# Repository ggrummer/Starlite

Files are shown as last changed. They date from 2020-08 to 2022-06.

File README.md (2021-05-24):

# Starlite
6 and 8-point stars using an FPGA to produce numerous patterns via a simple instruction set.
One doesn't need to know anything about FPGAs to create your own custom displays.
Refer to the "Documents" directory for project documents.
The Eagle directory has the schematic and the board design files.
The Mechanical directory has the 2D CAD files for laser cutting acrylic into star shapes, the 3D CAD files for the optional back covers and 3D CAD files for optional side covers.
The SolUP12 directory has all the FPGA files for the no longer recommended Lattice iCEcube2 build enviorment.
The SolRadi directory has all the FPGA files for the recommended Lattice Radiant build enviorment.

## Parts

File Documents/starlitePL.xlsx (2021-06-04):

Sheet: Assy Parts List
Starlite Assembly Parts List
Description | Qty | Manufacture | Part Number | Distributer | Cost | Comment
Outer Acrylic | 1 | Pololu | 7328, 1/8" | Pololu | $22.55
Inner Acrylic | 1 | Pololu | 7328, 1/16" | Pololu | $22.55 | See Notes Below
Screw, Polycarb, 4-40, 3/8" | 8 | Essentra Comp | 010440W037PC | Digi-Key | $4.88
Standoff, Nylon, 4-40, 5/8" | 4 | Essentra Comp | 15TSP036 | Digi-Key | $3.40
NeoPixel RGB Strip 60 LEDs | 1 | Sparkfun | COM-14730 | Digi-Key | $14.95 | See Notes Below
PCB | 1 | OSH Park | STARLITEMAIN | OSH Park | $15.49 | 1/3 of order
PCB Parts |  |  |  |  | $34.14
Total |  |  |  |  | $117.96
USB Micro Wall Adapter | 1 | CUI | SWI10-5-N-MUB | Digi-Key | $8.50 | Optional
Notes: | Inner acrylic can be 1/8" thick, but it will be harder to solder the LED strips to the pin headers
 | Each point of a star uses a strip of 7 LEDs, so the 60 LED strip must be cut up
 | Sparkfun LED Strip is obsolete. Any 60 LED per meter strip, 4 or 5mm wide, and uses SK6812 or
 |  | WS2812B LEDs will work.
 |  | Alternates are:
 |  | Manufacture | Part Number | Distributer | Cost | Comment
 |  | SuperLightingLED | SK6812-3535-60W5 | Direct, China | $9.98 | White, 1 meter
 |  | Alitove | AL2812WH120NP2M5MM | Amazon | $16.99 | White, 2 meters
 |  | H/A | B093CWF55Y | Amazon | $17.69 | White, 2 meters

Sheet: PCB Parts List
Starlite PCB Parts Parts List |  |  |  |  |  | Rev 5
Description | Ref Des | Qty | Manufacture | Part Number | Distributer | Cost
iCE40UP FPGA Daughter Board | U1 | 1 | TinyVision | Upduino-V3.0 | Tindie | $24.00
8-bit Transceiver 20DIP | U2 | 1 | TI | SN74AHCT245N | Digi-Key | $0.53
USB Micro B Breakout Board | JP9 | 1 | Adafruit | 1833 | Digi-Key | $1.50
Diode, Schottky, Axial, 1A, 20V | D1 | 1 | MCC | 1N5817-TP | Digi-Key | $0.32
Cap 0.1uF, 50V X7R, Radial | C1, C2, C5 | 3 | Kemet | C326C104K5R5TA | Digi-Key | $0.66
Cap 100uF, 16V, Alum, Radial | C3, C4 | 2 | Rubycon | 16ML100MEFC6.3X7 | Digi-Key | $0.44
Switch, Tactile | S1, S3 | 2 | TI | 1-1825027-1 | Digi-Key | $0.52
Switch, Slide | S2 | 1 | C&K | L102021ML04Q | Digi-Key | $2.09
Pin Header, 3pin, 50 mil Pitch | JP1-8 or JP11-16 | 8 | Preci-Dip | 850-80-003-10-001101 | Digi-Key | $4.08
 |  |  |  |  |  | $0.00
Total |  |  |  |  |  | $34.14
Notes: | 8-point star uses JP1-8
 | 6-point star uses JP11-16

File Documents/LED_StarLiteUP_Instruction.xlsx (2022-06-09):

LED Lite Instruction Creator |  |  |  | Rev 1.8
By: Grant Grummer
Command | 4 | See below | One Byte
Address/Duration/Loops | 8 | See below | 6/8/8 Bits
Brightness/Qty/Control | 64 | See below | One Byte
Blue | 0 | 15 max | One Nibble
Green | 3 | 15 max | One Nibble
Red | 15 | 15 max | One Nibble
Instruction in Hex |  | 4084003F | 32 Bits
 | [31:28] | [27:20] | [19:12] | [11:0]
Instruction Description | Command Number | Address/Duration/ Loops/Hours On | Brightness/Qty/Hours Off/ Control | Color/Hours Delayed
Blackout display | 0
Delay 1 | 1 | Duration, 255 max, 0 is a random delay
Finish 3 | 2
Set one lite with random address and/or color | 3 | Address = 0 to 63, random = 64 | Brightness | 0 = current
 |  |  |  | 1 = new 4
 |  |  |  | 3 = new no rep 6
Set one lite | 4 | Address, 0 to 63 | Brightness | Color
Chase (lites rap around) | 5 | Offset size [25:20] 2 | 0 = decrement lite offset,
 |  |  | 1 = increment lite offset,
 |  |  | 2 = zero lite offset
Reserved | 6
Fade in & out | 7 | Incr lower limit [25:24] | 0 = disable fading,
 |  | Decr upper limit [23:22] | 1 = enable fading
 |  | Speed Up [21:20]
Loop the previous x number of instructions | 8 | Number of loops, 255 for infinite loop | Qty of instructions = loop instruction line number - start instruction number. 255 max instructions.
Set random color palette | 9 | Color number 0 to 15 |  | Color
Offset lite instruction by 1 to each star point, block points | 10 |  | 0 = disable point offset, | Block individual points from changing
 |  |  | 1 = enable point offset
Rainbow colors | 11 |  | 0 = disable,
 |  |  | 1 = enable
Reserved | 12
Auto Timeout 5 | 13 | Hours on: 31 max, 0 always on (default) | Hours off: 31 max, 0 once off stay off (default) | Hours delayed (off): 31 Max, 0 (default)
 | 14
 | 15
 |  | [11:8] | [7:4] | [3:0]
Colors In Instructions 4 & 9 |  | Blue | Green | Red
Notes
1 | Duration: | 255 max times = 5.12 mSeconds, A duration of 8 is fast
2 | For backwards compatability, an offset size of 0 = 1. All others = number entered
3 | All instruction sets must end with a finish instruction
4 | Uses random color palette in Instruction 9
5 | Setup before issuing the display instruction set
6 | Uses random color palette in Instruction 9, excludes repeating colors

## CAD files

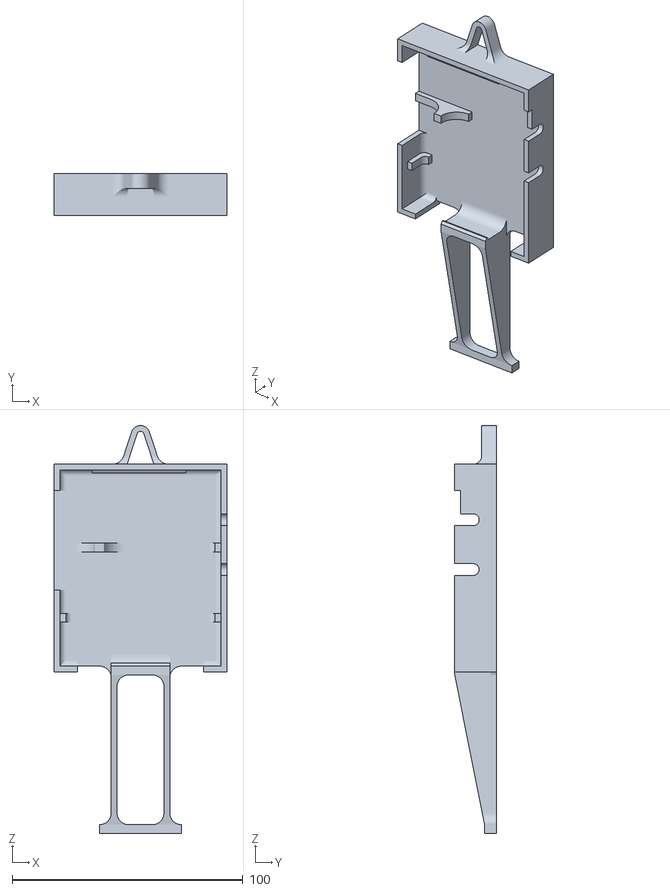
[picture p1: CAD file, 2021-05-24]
Mechanical/BackCover6PointStar/StarCoverMain6c.stl
74.9 x 18.0 x 177.0

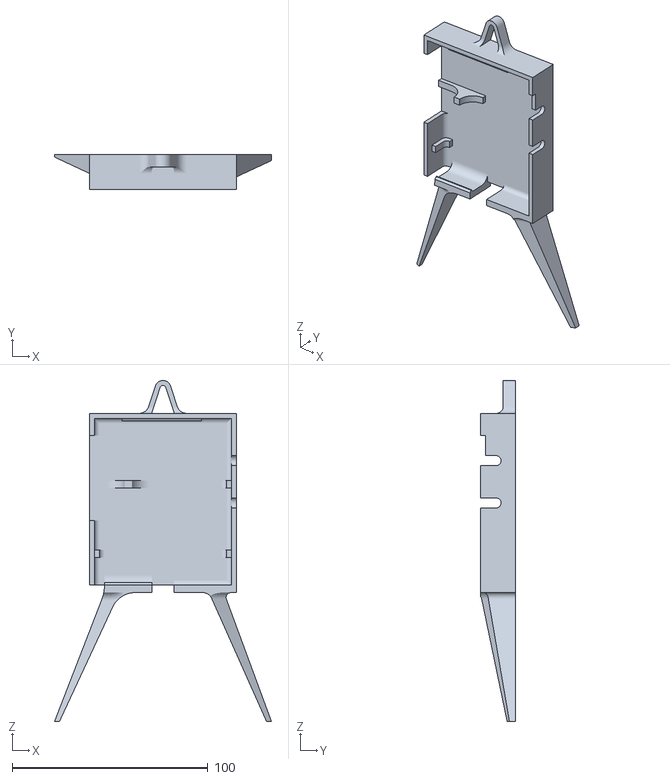
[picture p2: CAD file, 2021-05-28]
Mechanical/BackCover8PointStar/StarCoverMain8c.stl
110.7 x 18.0 x 174.0

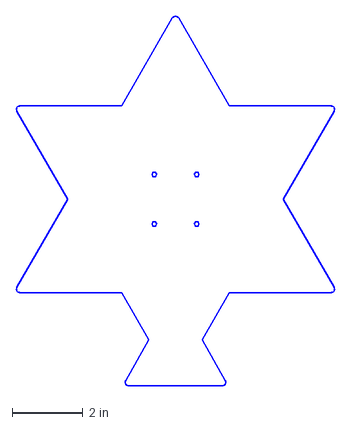
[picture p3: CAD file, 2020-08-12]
Mechanical/Acrylic6PointStar/OutStar6b305.dxf
9.01 x 10.5 in

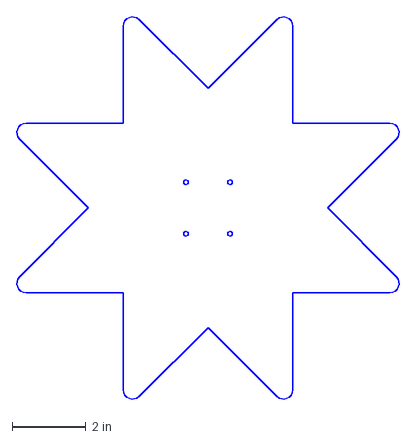
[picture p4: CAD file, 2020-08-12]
Mechanical/Acrylic8PointStar/OutStar8Sym.dxf
10.4 x 10.4 in

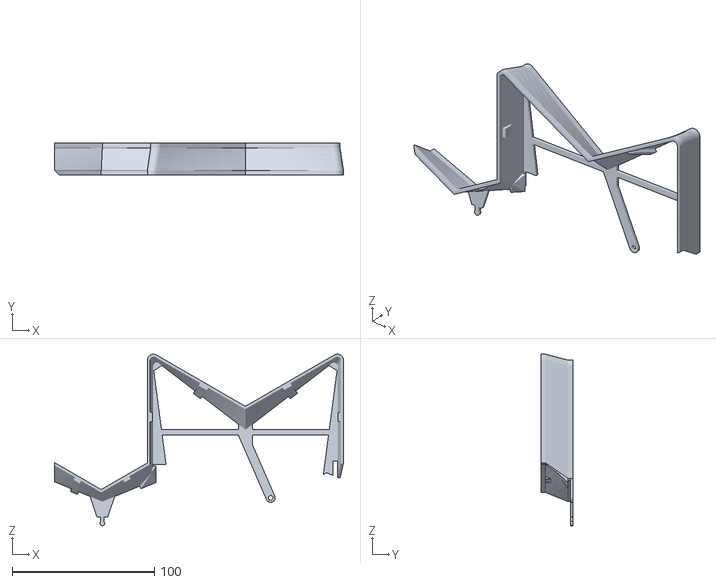
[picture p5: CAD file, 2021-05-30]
Mechanical/Sides6pointStar/Right6All.stl
202.9 x 22.6 x 120.5

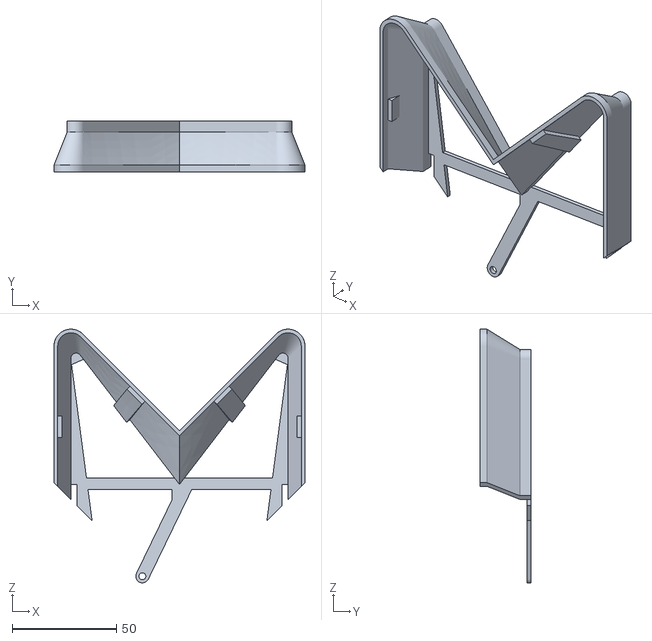
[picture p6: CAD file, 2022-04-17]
Mechanical/Sides88PointStar/Right88Side.stl
120.3 x 24.4 x 121.6

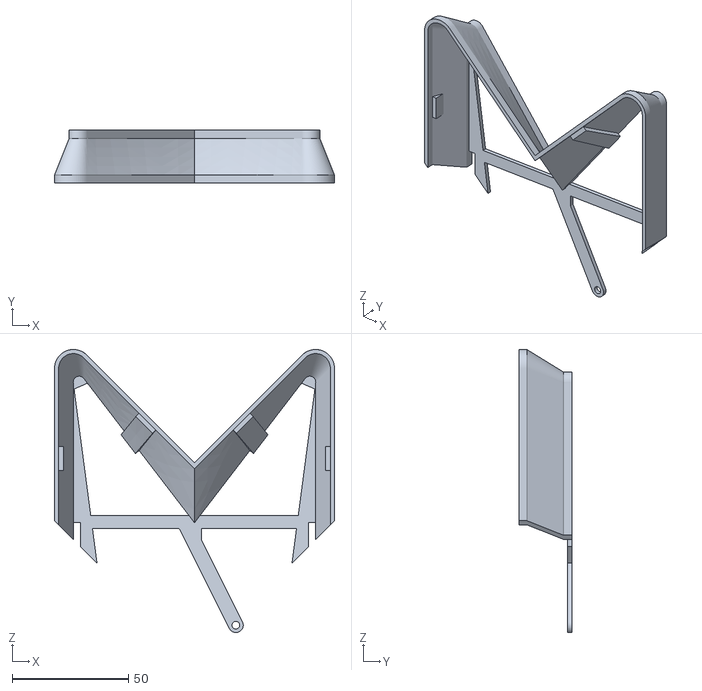
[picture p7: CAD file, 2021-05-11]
Mechanical/Sides8PointStar/Left8Side.stl
120.3 x 22.6 x 121.6

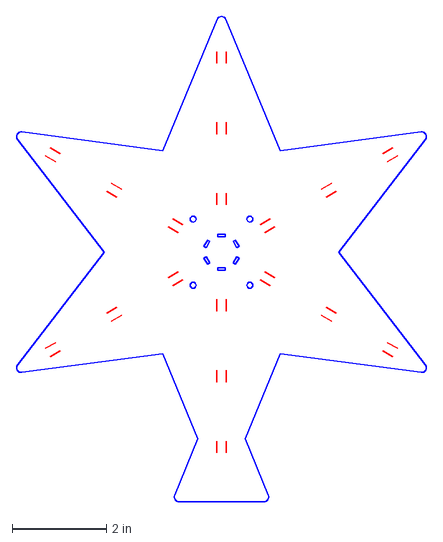
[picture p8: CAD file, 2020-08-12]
Mechanical/Acrylic6PointStar/InStar6c305.dxf
8.69 x 10.3 in

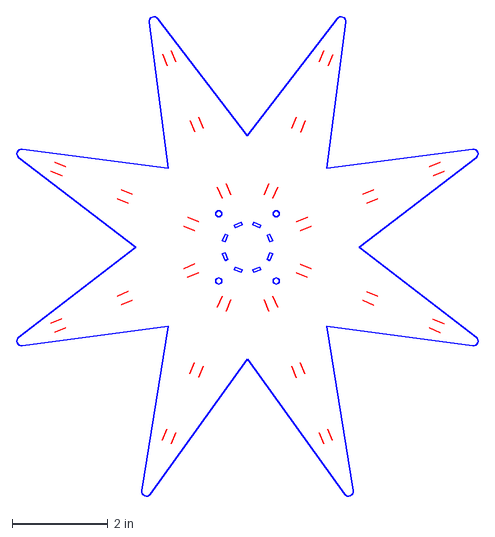
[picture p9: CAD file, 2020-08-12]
Mechanical/Acrylic8PointStar/InStar8SymC.dxf
9.64 x 10.0 in

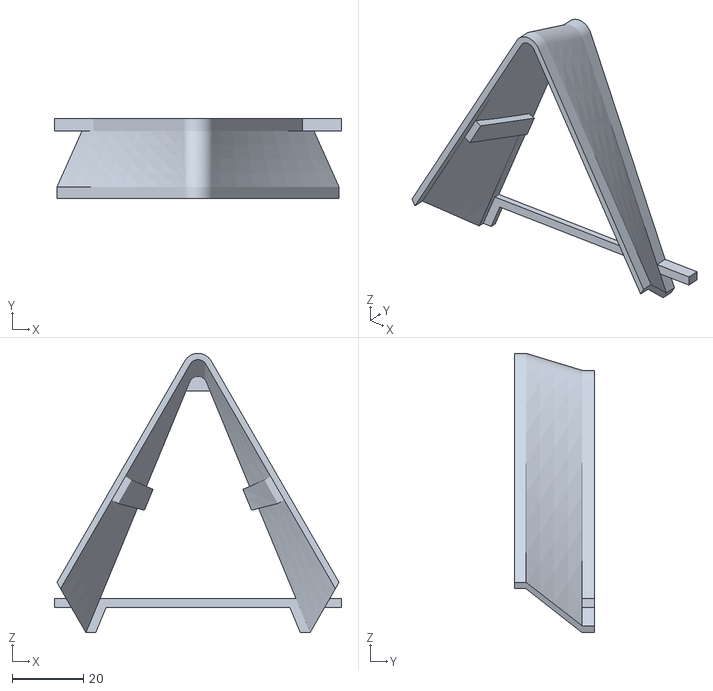
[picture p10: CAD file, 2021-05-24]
Mechanical/Sides6pointStar/Top6Side2.stl
80.8 x 22.6 x 78.7

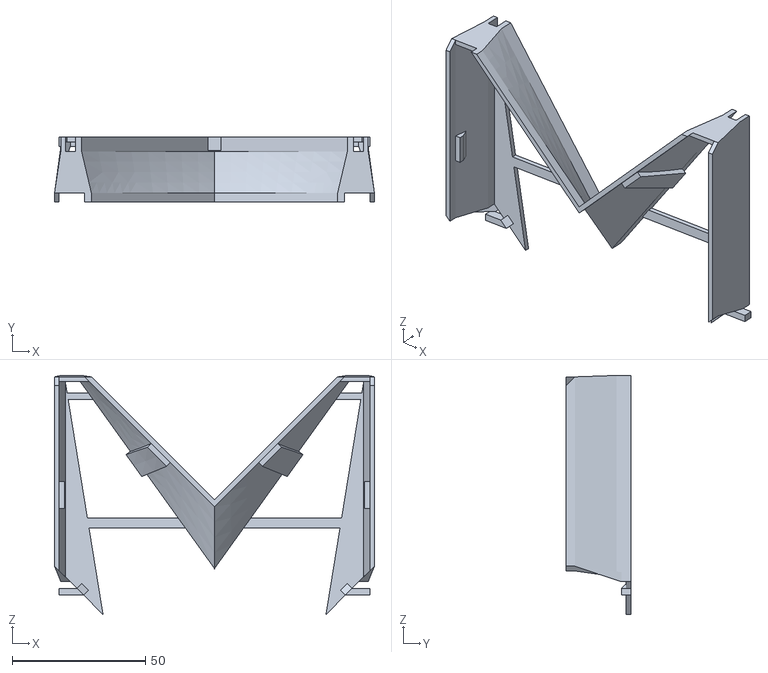
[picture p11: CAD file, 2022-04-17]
Mechanical/Sides88PointStar/Bot88Side.stl
120.3 x 24.4 x 89.9

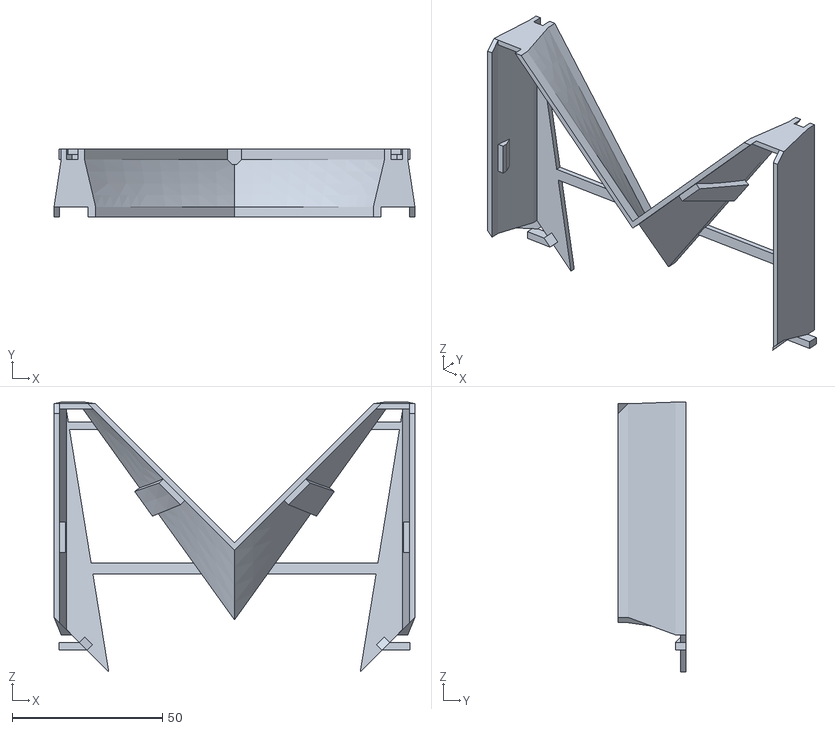
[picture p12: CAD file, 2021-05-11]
Mechanical/Sides8PointStar/Bot8Side.stl
120.3 x 22.6 x 89.9

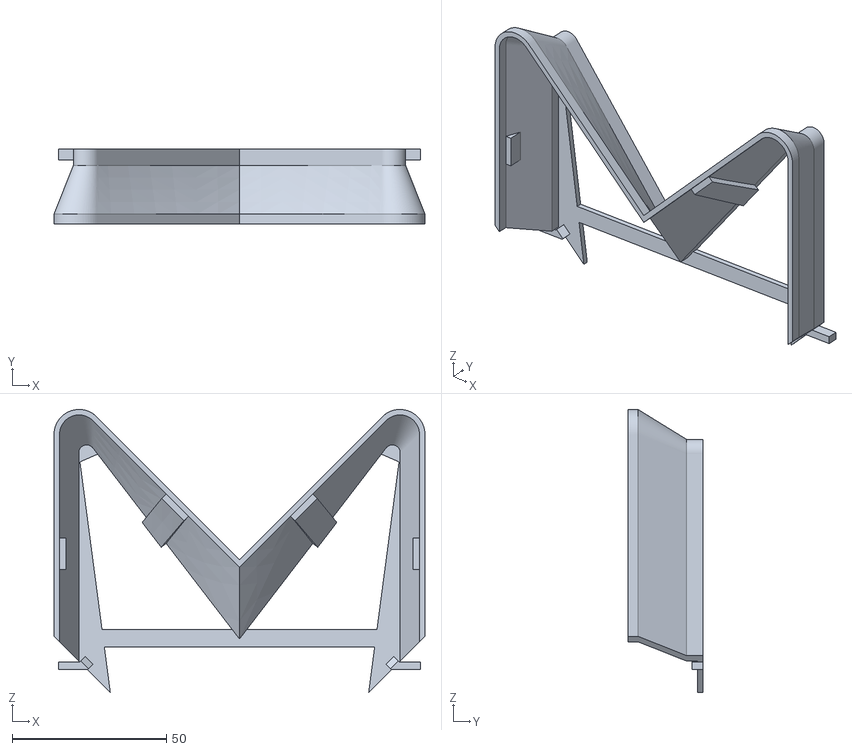
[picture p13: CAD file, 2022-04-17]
Mechanical/Sides88PointStar/Top88Side.stl
120.3 x 24.4 x 91.8

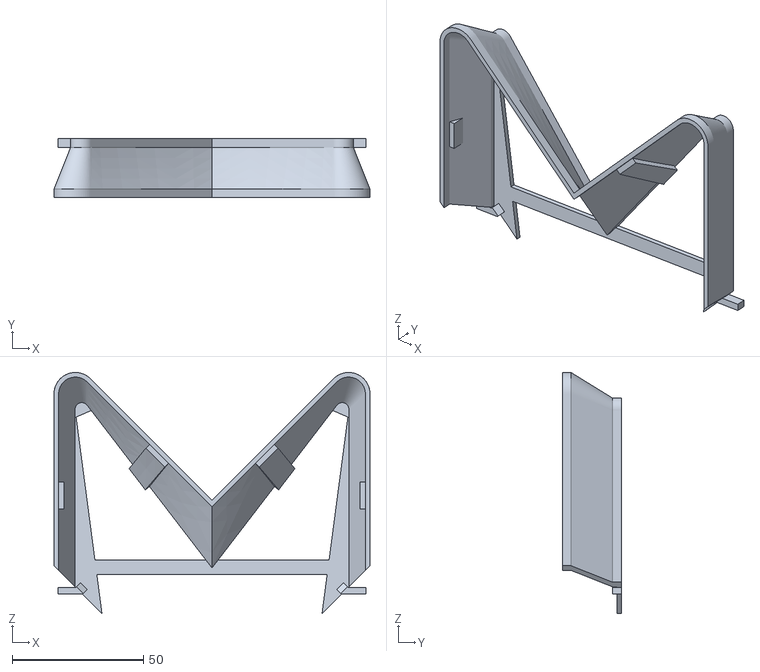
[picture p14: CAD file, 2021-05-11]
Mechanical/Sides8PointStar/Top8Side.stl
120.3 x 22.6 x 91.8

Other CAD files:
Mechanical/Sides6pointStar/Left6All.stl
Mechanical/Sides8PointStar/Right8Side.stl
Mechanical/Sides88PointStar/Left88Side.stl

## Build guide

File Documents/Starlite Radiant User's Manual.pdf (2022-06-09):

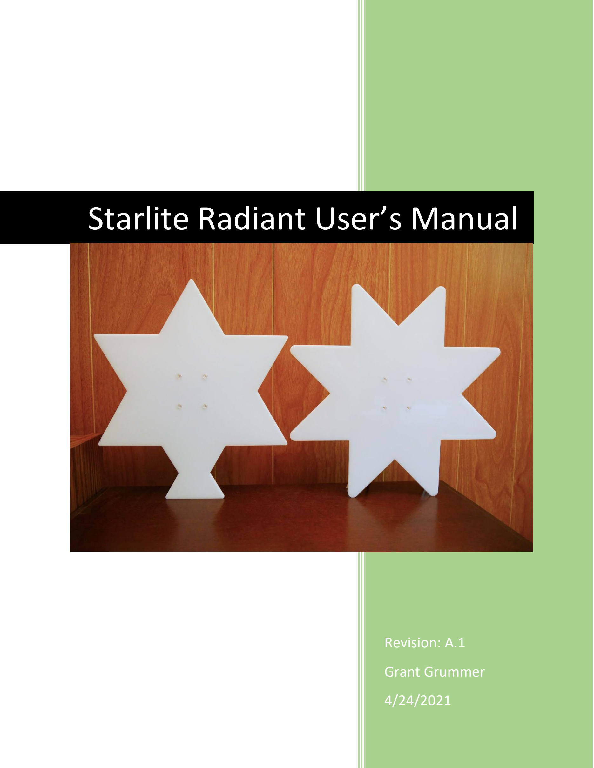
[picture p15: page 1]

## Grant Grummer

4/24/2021

# Starlite Radiant User’s Manual

## Revision: A.1

## Starlite User’s Manual

## Table of Contents

## Introduction

Welcome to the Starlite User’s Manual. Starlite can be constructed as a 6 or 8-point star. They’re approximately 10 inches tall. They consist of outer and inner translucent acrylic star shapes, tri-color LED strips, a circuit board, and the hardware to connect them together. An optional 3D printed back cover can also be made, for a more finished look.

Starlite uses the tri-color LED strips to produce different light displays. Starlite is programmable, so the displays are only limited by your imagination. No previous software knowledge is required. A set of default light displays along with an introduction to Starlite can be viewed at either of the following links:

https://youtu.be/trDGcNV_JYw

https://vimeo.com/465602794

A small set of display specific instructions are used to create different display patterns. There are up to 16 possible instructions. Not all of these instructions are defined at the time of this writing and are available for those who wish to dive deeper into this project.

The circuit board contains all the electronic hardware needed to drive the LED strips. The brain of the hardware is a Lattice iCE40 Ultra Plus 5K FPGA (Field Programmable Gate Array). It, along with programming and other support logic, is on the UPduino v3.0 (https://www.tindie.com/products/tinyvision_ai/upduino-v30-low-cost-lattice-ice40-fpga-board/?pt=ac_prod_search) low cost daughter board. It’s mounted onto the StarLiteMain board. The StarLiteMain board contains switches, power connector and interface hardware.

Starlite is controlled via three switches. The power switch enables/disables power from the power input micro USB connector. The upper pushbutton switch selects one of four display instruction sets. Each set can have up to 256 instructions. The lower pushbutton switch selects different brightness levels.

## Starlite Design Environment

In order to program Starlite, one must first setup a design environment. Refer to the “Starlite Radiant Installation and Setup” document for instruction on how to set it up. The rest of this document assumes this step has been completed.

## Building the Design

The Lattice Radiant design environment is used to build the design. A full build is performed by clicking on the “Run All” triangle. The boxes to the right of the “Run All” triangle all turn green (with a check mark) once the design has been built. See Figure 1.

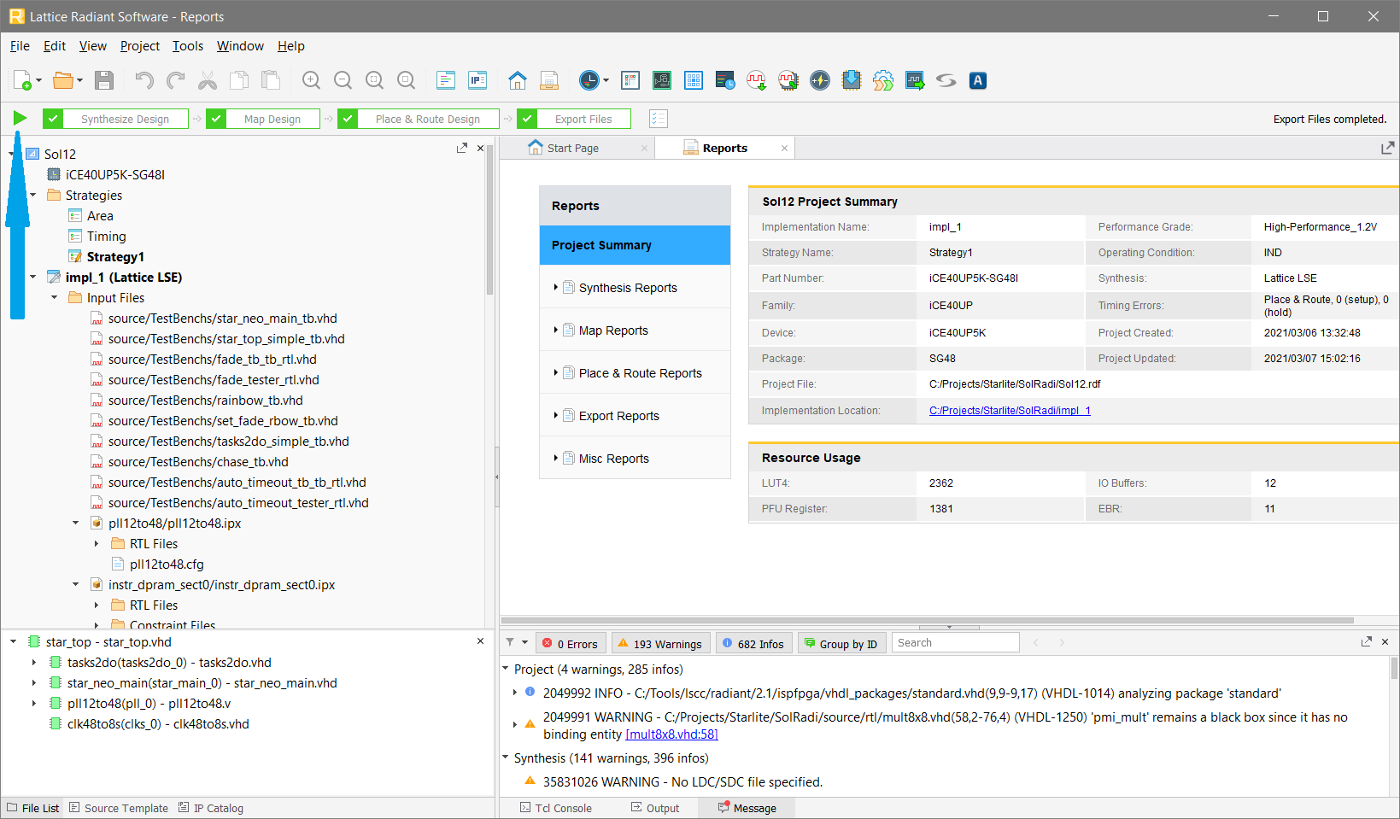
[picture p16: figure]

Figure 1: Run All

## Custom Displays

A great way to get started with making your own custom displays is to build new display instruction sets. One doesn’t need to know anything about FPGAs or software to do this. Use the supplied “LED_StarLiteUP_Instruction” spreadsheet to create each instruction. Use a text editor to combine the new instructions into a set of instructions. Refer to the supplied example display instruction sets, in the “Patterns” folder, to see how this looks. Remember to end each instruction set with the Finish instruction!

There are 4 memories in Starlite, each contain one display pattern. They are selected via the pattern pushbutton switch. Each memory can be loaded with a new pattern by double clicking on inst_dpram_sect0, 1, 2 or 3 as shown in Figure 2.

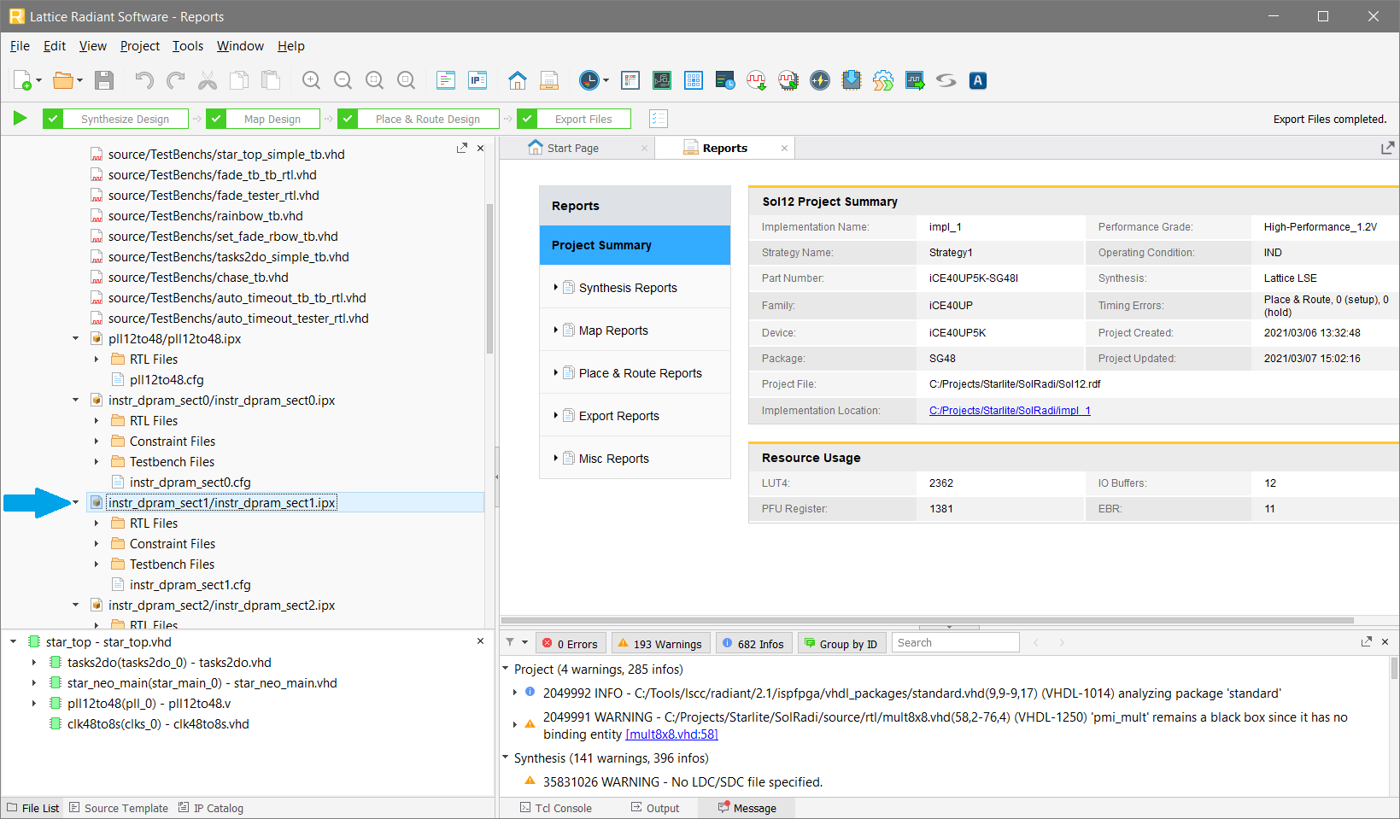
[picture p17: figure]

Figure 2: Display Patterns

Replace the current instruction set with your new instruction set by clicking on “…” and navigating to that instruction as highlighted in Figure 3.

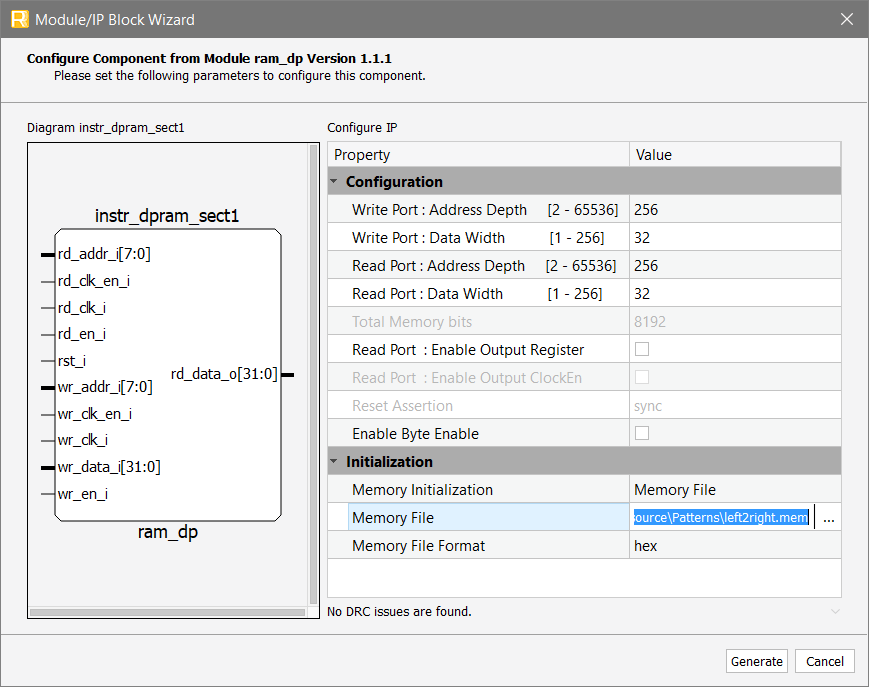
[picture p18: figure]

Figure 3: Replacing Display Pattern

Click in the “Generate” button (at the bottom of the window) to replace the display pattern. After that completes, re-build the design as outlined in the Building the Design section.

## Programming Starlite

Starlite can be programmed from the Radiant program or via a standalone programmer.

### Programmer Access Through Radiant

From Radiant, click on the programming icon as shown in Figure 4.

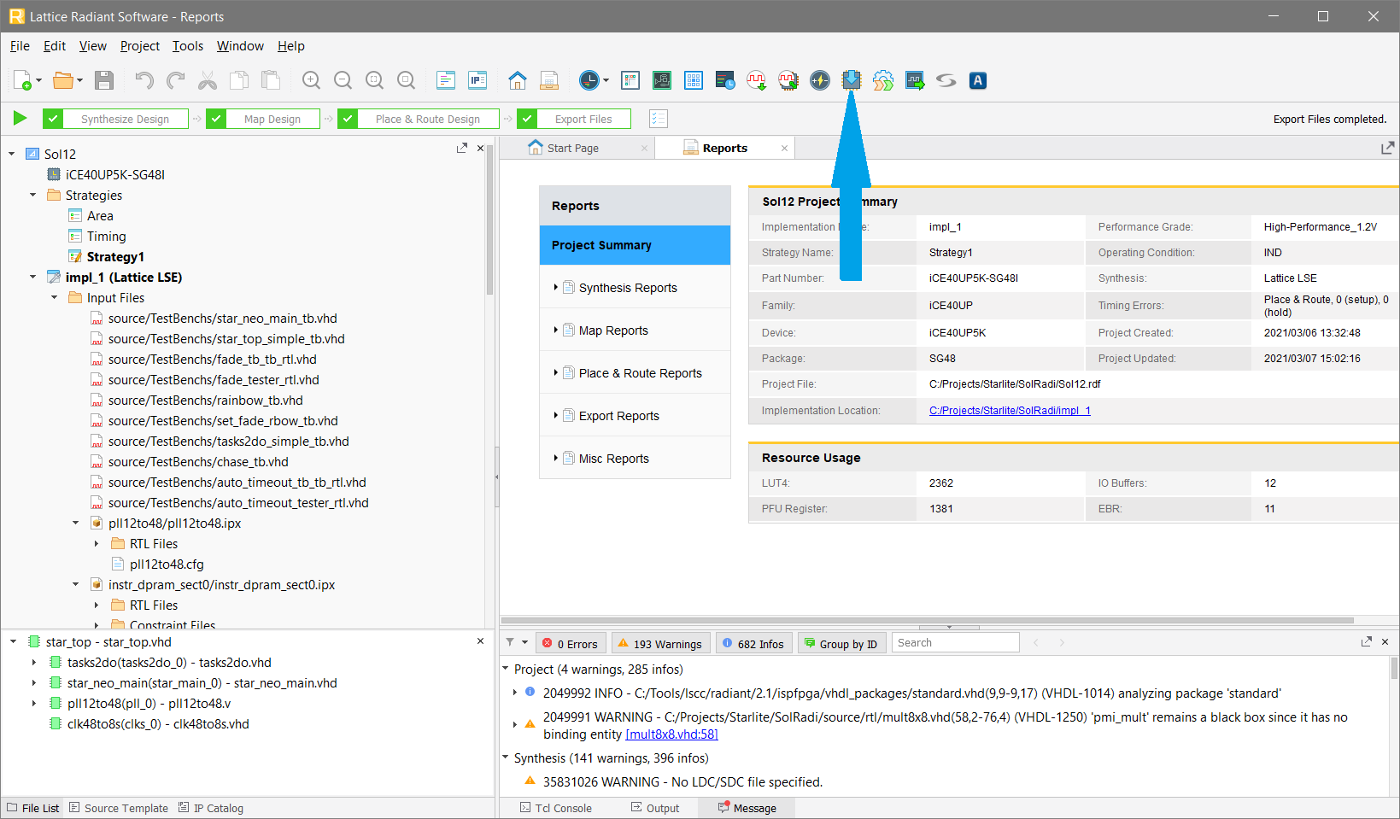
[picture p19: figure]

Figure 4: Programming Icon

### Standalone Programmers

There are many programmers that can be used to program Starlite. One is the Radiant Programmer Standalone (https://www.latticesemi.com/Products/DesignSoftwareAndIP/FPGAandLDS/Radiant) and the other is the Diamond Programmer Standalone. (http://www.latticesemi.com/en/Products/DesignSoftwareAndIP/ProgrammingAndConfigurationSw/Programmer.aspx) They’re both very similar. The following steps can be used with the Radiant Programmer to program Starlite. The Diamond Programmer steps may be slightly different.

1. Connect the micro USB port on the UPDuino v3.0 to your PC
2. Open the Radiant Programmer
3. Click `Detect Cable` then `OK`
4. After scanning, select `Generic JTAG Device` and `Select iCE40 UltraPlus`
5. Under `Device` click iCE40UP3K and change it to iCE40UP5K
6. Under `Operation` double click `Fast Program` and change `Target Memory: ` to `External SPI Flash Memory`
7. Select your `*.hex` programming file under `Programming file`.
8. Configure the following `SPI Flash Options`
a. Winbond
b. W25Q32JV
c. 208mil 8-pin SOIC
9. Click `Load from File` under `SPI Programming` to get load size
10. Click OK
11. Click `Run` -> `Program Device`

## Instructions

As previously noted, there are up to 16 possible instructions. Most are specifically tailored for RGB LED strings. Instructions are 32-bits long. All instructions start with a command. Some commands are followed by additional fields. A detailed description of each instruction is presented in the following sections. Note all bits of the instructions are zeroed at powerup unless otherwise noted.

The LED_StarLiteUP_Instruction spreadsheet provides an easy way to create instructions. It allows instructions to be build using decimal number and automatically provides the hexadecimal value (of the instruction) needed by the FPGA. Optionally, a detailed look at each bit, in each instruction, is provided in the rest of this section.

### Instruction 0: Blackout Display

Blackouts the entire display.

31 | 28 | 27 | 0
CMD0 | Unused | Unused | Unused | Unused | Unused
Bits | Name | Function
[31:28] | CMD0 | Blackouts all the LEDs in the string(s). All bits must be zero.
[27:0] | Unused | Not defined

### Instruction 1: Delay

Adds a programmable time delay. Each additional count adds 5.12 mSeconds. The maximum count is 255 (0xFF). A count a zero creates a random delay.

31 | 28 | 27 | 20 | 19 | 0
CMD1 | DLY | Unused | Unused | Unused | Unused
Bits | Name | Function
[31:28] | CMD1 | Programmable delay. Value = 1
[27:20] | DLY | Delay count. Max = 255 (0xFF). All zeros create a random count.
[19:0] | Unused | Not defined

### Instruction 2: Finish

All instruction sets must end with a finish command!

31 | 28 | 27 | 0
CMD2 | Unused | Unused | Unused | Unused | Unused
Bits | Name | Function
[31:28] | CMD2 | Informs the FPGA that the present instruction set is finished. Value = 2

[27:0] | | Unused | | Not defined

### Instruction 3: Set Random LED

Used to set one LED at a random location/address and/or color. The random color is selected from the 16 colors in the color palette (see Instruction 9: Set Color Palette).

31 | 28 | 27|26| 25 | 20 | 19 | 12 | 11 | 2 | 1 | 0
CMD3 | U | R | | ADDR | BRITE | Unused | Unused | Unused | P |N
Bits | Name | Function
[31:28] | CMD3 | Sets one LED. Value = 3
[27] | U | Unused, not defined
[26] | R | Random LED address 0 = bits [25:0] specify address of LED 1 = random LED address generated
[25:20] | ADDR | Specific LED address when [26] = 0. Values 0 to 63 (0x3F)
[19:12] | BRITE | Set the brightness of the LED. Values 0 to 255 (0xFF)
[11:2] | Unused | Not defined
[1] | P | 1 = excludes repeated colors when bit 0 is set to 1
[0] | N | 0 = use the same color as used in the last CMD3. That color was the one last selected from the color palette. 1 = use the next color in the color palette.

### Instruction 4: Set LED

Used to set one LED’s address and color.

31 | 28 | 27 26 | 25 | 20 | 19 | 12 | 11 | 8 | 7 | 4 | 3 | 0
CMD4 | U | | ADDR | BRITE | BLUE | GREEN | RED
Bits | Name | Function
[31:28] | CMD4 | Sets one LED. Value = 4
[27:26] | U | Unused, not defined
[25:20] | ADDR | Specific LED address. Values 0 to 63 (0x3F)
[19:12 | BRITE | Set the brightness of the LED. Values 0 to 255 (0xFF)
[11:8] | BLUE | Sets the amount of blue. Value 0 to 15 (0xF)
[7:4] | GREEN | Sets the amount of green. Value 0 to 15 (0xF)
[3:0] | RED | Sets the amount of red. Value 0 to 15 (0xF)

### Instruction 5: Chase

Adds an offset to all LED addresses. Increments or decrements that address along with their brightness and color. The offset wraps around at maximum numbers of LEDs per string.

31 | 28 | 27 26 | 25 | 20 | 19 | 14|13|12 | 11 | 0

CMD5 | U | | SIZE | Unused | | Z | ID | Unused | Unused | Unused
Bits | Name | Function
[31:28] | CMD5 | Increments or decrements every LED’s address by one. Value = 5
[27:26] | U | Not defined
[25:20] | SIZE | Offset size. A size of 0 = 1. All others = number entered
[19:14] | Unused | Not defined
[13] | Z | 0 = do not zero LEDs address offset 1 = zeros LEDs address offset (ID value ignored)
[12] | ID | 0 = decrement offset 1 = increment offset
[11:0] | Unused | Not defined

### Instruction 6: Reserved

Do not use. It’s used in other versions of this project.

31 | 28 | 27 | 0
CMD6 | Unused | Unused | Unused | Unused | Unused
Bits | Name | Function
[31:28] | CMD6 | Reserved. Value = 6
[27:0] | Unused | Not defined

### Instruction 7: Fade In and Out

Fades all LEDs brightness. Increments and then decrements all LEDs brightness.

31 | 28 | 27 26|25 24|23 22|21 20 | 19 | 13|12 | 11 | 0
CMD7 | U | LLIM| ULIM| SPD | Unused | | EF | Unused | Unused | Unused
Bits | Name | Function
[31:28] | CMD7 | Increments or decrements every LED’s address by one. Value = 7
[27:26] | U | Unused, not defined
[25:24] | LLIM | Limits how low the brightness value can go
[23:22] | ULIM | Limits how high the brightness value can go
[21:20] | SPD | Speeds up the incrementing and decrementing
[19:13] | Unused | Not defined
[12] | EF | 0 = disable fading once decrement reaches its lowest value 1 = enables fading starting at its lowest value
[11:0] | Unused | Not defined

### Instruction 8: Loop

Loop the previous x number of instructions.

31 | 28 | 27 | 20 | 19 | 12 | 11 | 0
CMD8 | LOOPS | QTY | Unused | Unused | Unused
Bits | Name | Function
[31:28] | CMD8 | Repeats previous instructions. Value = 8
[27:20] | LOOPS | Sets the number of times a loop is executed. A value of 255 (0xFF) is a continuous loop.
[19:12] | QTY | Quantity of instruction to repeat. Subtract the start instruction from the loop instruction line number.
[11:0] | Unused | Not defined

### Instruction 9: Set Color Palette

Storage location for 16 definable colors. Used in conjunction with Instruction 3: Set Random LED. A set of predefined colors are loaded at powerup. Use this instruction to change them.

31 | 28 | 27 | 24 | 23 | 20 | 19 | 12 | 11 | 8 | 7 | 4 | 3 | 0
CMD9 | Unused | CNUM | Unused | BLUE | GREEN | RED
Bits | Name | Function
[31:28] | CMD9 | Sets one LED. Value = 9
[27:24] | Unused | Not defined
[23:20] | CNUM | Specific palette address. Values 0 to 15 (0xF)
[19:12] | Unused | Not defined
[11:8] | BLUE | Sets the amount of blue. Value 0 to 15 (0xF)
[7:4] | GREEN | Sets the amount of green. Value 0 to 15 (0xF)
[3:0] | RED | Sets the amount of red. Value 0 to 15 (0xF)

### Instruction 10 (0xA): Instruction Offset & Block

This instruction does two somewhat unrelated, Starlite specific, functions. The first is to offset the instruction given to each LED string by one. The second is to block any number of LED strings from getting an instruction. This blocking is only available for up to the first 12 points.

31 | 28 | 27 | 13 |12 | 11 | 10 | 9 | 8 | 7 | 6 | 5 | 4 | 3 | 2 | 1 | 0
CMD10 | Unused | Unused | |PO | B11|B10|B9|B8 | B7|B6|B5|B4 | B3|B2|B1|B0
Bits | Name | Function
[31:28] | CMD10 | Increments or decrements every LED’s address by one. Value = 10 (0xA)
[27:13] | Unused | Not defined
[12] | PO | 0 = disable point offset 1 = enable point offset
[11] | BLK11 | 0 = unblock point 11

| | 1 = block point 11
[10] | BLK10 | 0 = unblock point 10 1 = block point 10
⁞ | ⁞ | ⁞
[0] | BLK0 | 0 = unblock point 0 1 = block point 0

### Instruction 11 (0xB): Rainbow

Transitions through the 12-bit color spectrum.

31 | 28 | 27 | 13|12 | 11 | 0
CMD11 | Unused | Unused | |ER | Unused | Unused | Unused
Bits | Name | Function
[31:28] | CMD11 | Increments or decrements every LED’s address by one. Value = 11 (0xB)
[27:13] | Unused | Not defined
[12] | ER | 0 = disable the transitions 1 = enables the transitions
[11:0] | Unused | Not defined

### Instruction 12 (0xC): Reserved

Do not use. It’s used in other versions of this project.

31 | 28 | 27 | 0
CMD12 | Unused | Unused | Unused | Unused | Unused
Bits | Name | Function
[31:28] | CMD12 | Reserved. Value = 12 (0xC)
[27:0] | Unused | Not defined

### Instruction 13 (0xD): Automatic Timeout

Automatically turns the LEDs on and off according to the following settings. The instruction set in use before the time “off” will resume once the time “on” is attained. One should set this up before issuing display instructions.

31 | 28 | 27 | 25 | 24 | 20 | 19 | 17 | 16 | 12 | 11 | 5 | 4 | 0
CMD13 | Unused | | HON | Unused | | HOFF | Unused | Unused | HDLY
Bits | Name | Function
[31:28] | CMD13 | Sets one LED. Value = 13 (0xD)
[27:25] | Unused | Not defined
[24:20] | HON | Hours on. “0” is always on. Values 0 to 31 (0x1F)

[19:17] | Unused | Not defined
[16:12] | HOFF | Hours off. “0” is once off stay off. Value 0 to 31 (0x1F)
[11:5] | Unused | Not defined
[4:0] | HDLY | Hours delayed (off). Value 0 to 31 (0x1F)

### Instruction 14 (0xE): Unused

Available for a new instruction.

31 | 28 | 27 | 0
CMD14 | Unused | Unused | Unused | Unused | Unused
Bits | Name | Function
[31:28] | CMD14 | Unused but available. Value = 14 (0xE)
[27:0] | Unused | Not defined

### Instruction 15 (0xF): Unused

Available for a new instruction.

31 | 28 | 27 | 0
CMD15 | Unused | Unused | Unused | Unused | Unused
Bits | Name | Function
[31:28] | CMD15 | Unused but available. Value = 15 (0xF)
[27:0] | Unused | Not defined

## Code Base

The code base consists of mostly VHDL modules, some Verilog modules, instantiated and inferred IPs. There are 5 instantiated cores.

One instantiated core is a PLL (Phase Lock Loop). It’s used for creating a 48 MHz clock from the 12 MHz oscillator on the daughter board. A separate module divides the 48 MHz clock down to the 8 MHz and 800 kHz clocks used in the design. The majority of the design runs at 800 kHz.

The 4 remain cores are 256 x 32 memories. Each core holds an instruction set for a display pattern.

## Block Diagram of Starlite Code

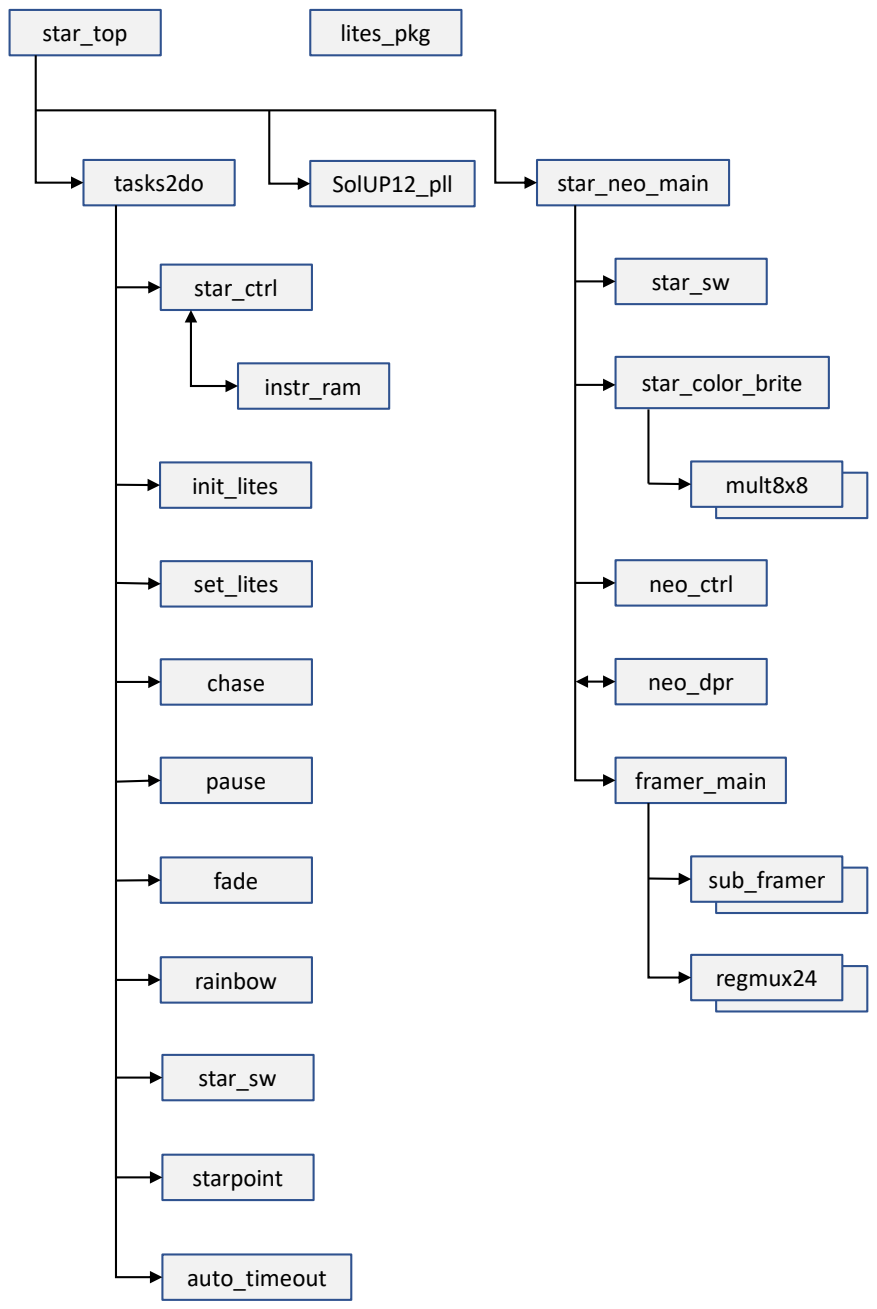
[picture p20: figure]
chase; pause; fade; rainbow; set_lites; star_top; tasks2do; star_ctrl; instr_ram; init_lites; lites_pkg; SolUP12_pll; star_neo_main; neo_ctrl; neo_dpr; framer_main; sub_framer; regmux24; star_sw; starpoint; star_color_brite; mult8x8; auto_timeout

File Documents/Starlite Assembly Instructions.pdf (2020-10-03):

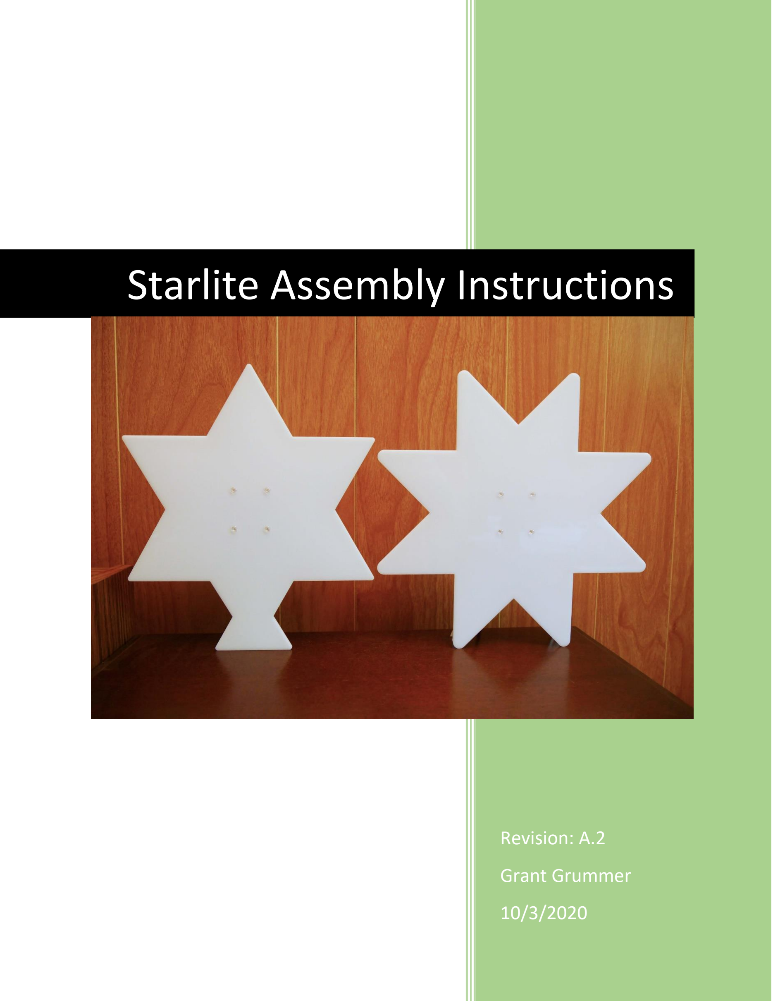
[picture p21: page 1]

## Grant Grummer

10/3/2020

# Starlite Assembly Instructions

## Revision: A.2

## Starlite Assembly Instructions

## Table of Contents

## Introduction

These instructions cover how to build a 6 or 8-point Starlite. Both are approximately 10 inches tall. They consist of outer and inner translucent acrylic stars shapes, tri-color LED strips, a circuit board, and the hardware to connect them together. An optional 3D printed back cover can also be made, for a more finished look.

It is assumed that all the parts, listed in the Starlite parts list, have been acquired before starting this assembly process.

## Tools required

The following list of tools are needed to build a Starlite:

- Soldering iron with a narrow tip (0.015” to 0.031” recommended)
- Thin solder (.031” to .020” recommended)
- Philips screwdriver, #1 size
- Wire cutters
- Small pliers

Though not required, thin solder wick is extremely handy to have available.

## Assembly Instructions

All through hole parts are used on Starlite in order to make the PCB assembly easy to do. With the exception of the 50 mil pin headers, that turns out to be correct. These pin headers require a steady hand or some decent optical magnification.

### Quick Instructions (for those who don’t like detailed instructions)

- All components are soldered onto the component side except the 50 mil pin headers
- The shorter pins of the headers supplied with the UPduino and the USB Breakout boards must be inserted into and soldered to the StarLiteMain board, not the long pins!
- Bend the power switch (S2) pins over some after soldering
- Solder the pin headers (onto the back of the PCB) last
- Plastic screws just need to be screwed in snug; they don’t need to be tighten much.

### Detailed, Step by Step Instructions

1. Solder the following components onto the components side of the StarLiteMain board first
a. Capacitors: C1 – C5
b. Diode: D1
c. Push buttons: S1 & S3
d. IC: U2

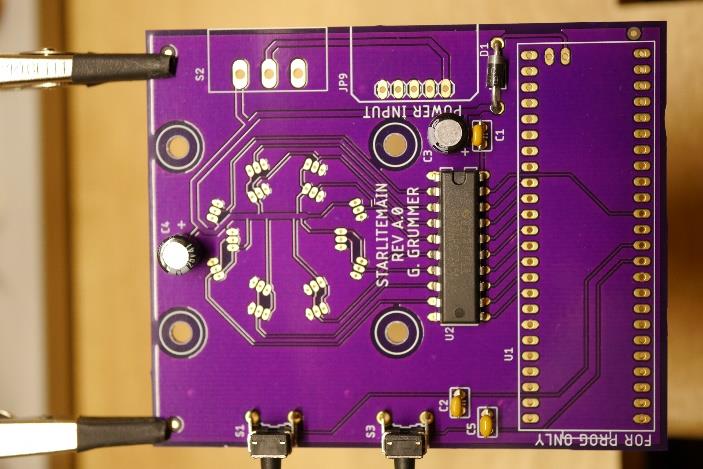
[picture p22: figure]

2. Apply a blob of solder across the OSC solder short on the UPduino board. It may be easier to do this step after the UPduino has been installed onto the StarLiteMain board.

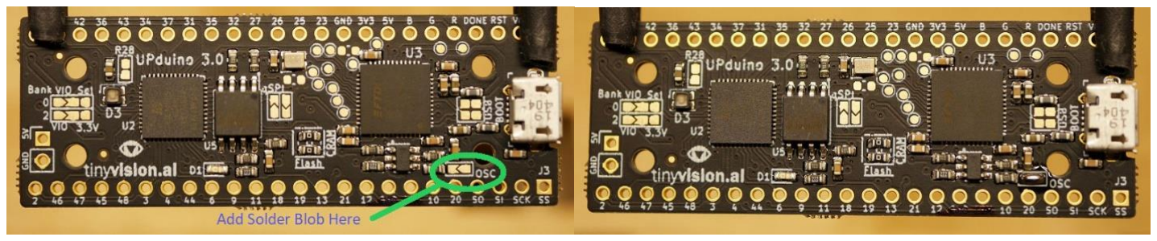
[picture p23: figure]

3. Solder the following components onto the components side of the StarLiteMain board next by following the instructions below.
a. UPduino board: U1
b. USB Micro B Breakout Board: JP9

Break off 2 header pins from one of the headers that came with the UPduino board. Insert those headers into the UPduino and StarLiteMain boards as shown in the following picture. The shorter pins of the headers supplied with the UPduino board must be inserted into the StarLiteMain board, not the long pins! The following pins, as labeled on the UPduino board, must be connected to the StarLiteMain board with the supplied headers. No harm will come to connecting additional pins.

- Pins 27, 25, 23, GND, 5V & GND (next to the VIO pin)
- Pins 6, 9, 11, 18, 19, 13, 21, 12 & GND (next to pin 10) (GND pin is not labeled in the picture)
- Pins 5V and GND (on the opposite side of the UPduino board’s USB connector)

Insert the header that came with the USB Breakout board into the StarLiteMain board as shown in the following picture. The shorter pins of the headers supplied with the USB Breakout board must be inserted into the StarLiteMain board, not the long pins!

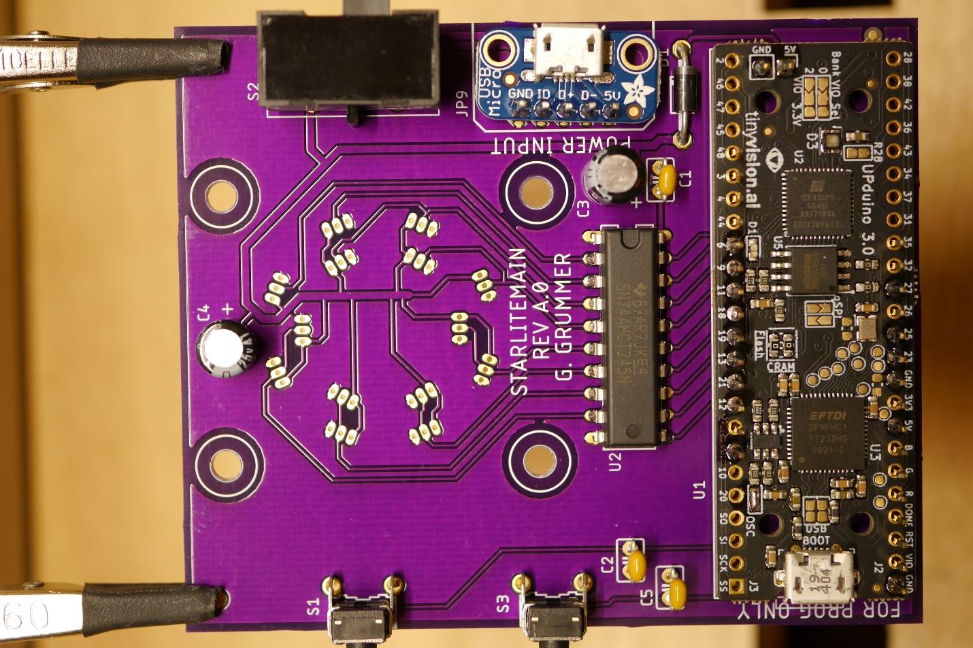
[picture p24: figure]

It’s easier to solder UPduino and the USB Breakout boards to the header which came with the board first, before soldering them to the PCB. Note not all of the pins on the UPduino need to be soldered (refer to the previous picture).

4. Solder the power switch (S2) to the board. Bend its pins over some (refer to the following picture)

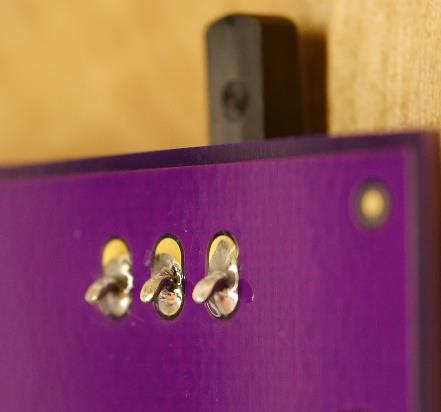
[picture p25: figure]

5. Install the 50 mil pin headers onto the back of the StarLiteMain board. It’s easiest to use the inner acrylic star to hold the headers to the board. Solder the pin headers to the board (refer to the following picture). Note the 8-point star configuration is shown.

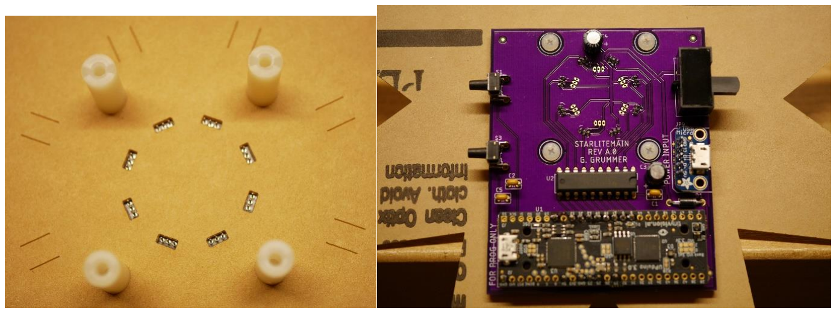
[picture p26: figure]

6. Remove inner star from the StarLiteMain board.
7. Remove the protective paper from both sides of the inner star. Tape will help in removing the protective paper.
8. Attach inner star with guide lines on one side and the StarLiteMain board on the other side. Use screws and standoffs to hold everything in place. Try to center the pin headers in the openings in the inner star (refer to the following picture). Note the 8-point star configuration is shown.

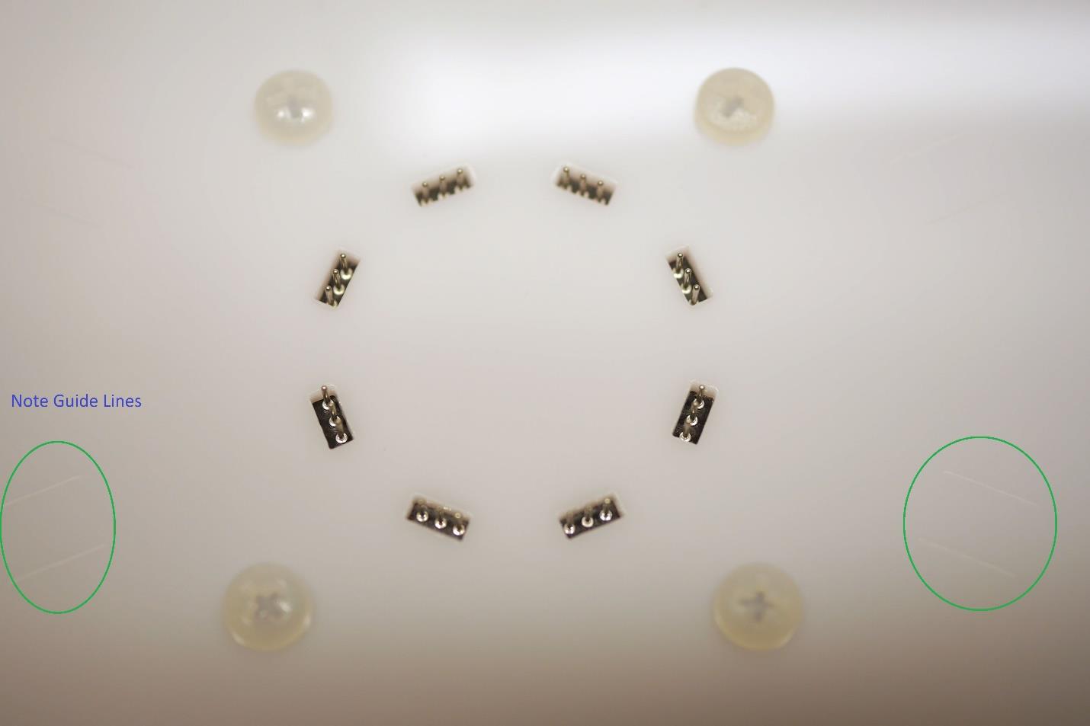
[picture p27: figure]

9. Cut the NeoPixel RGB LED strip into a length that has seven LEDs and seven caps. Make the cuts on the line in the middle of the exposed copper fingers. Straighten the strip the best you can.
10. Cut the exposed copper fingers off the end where the arrow point to (refer to the following picture). Pay close attention to the direction of the arrows on the strip.

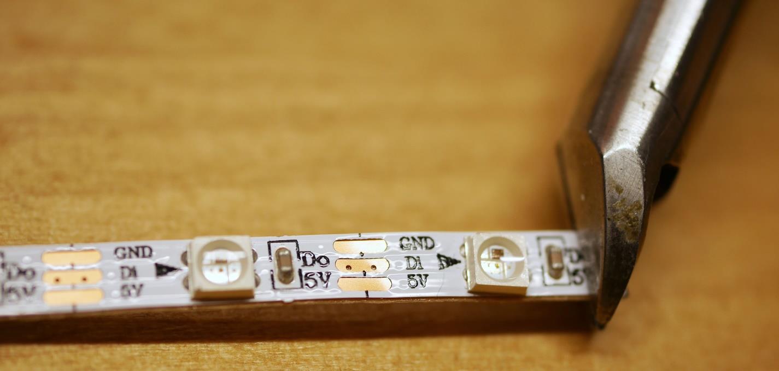
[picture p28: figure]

11. Make a slight bend at the exposed copper fingers at the end of the strip where the arrow points away from (refer to the following picture).

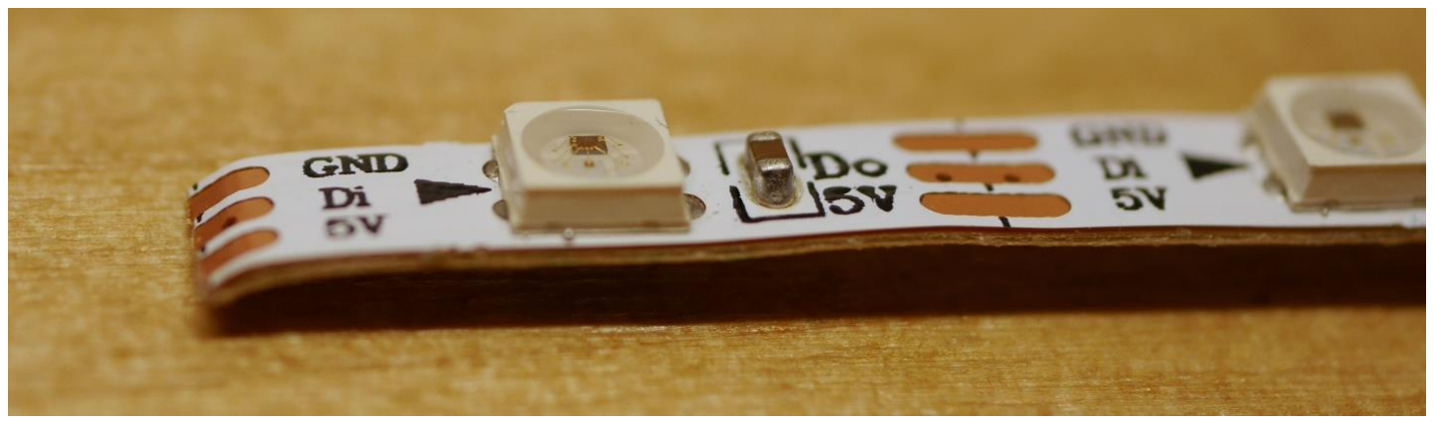
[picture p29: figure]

12. Start pealing the paper backing off the strip, starting at the end with the bend. Align the exposed copper fingers with a pin header so that the pins touch the exposed copper fingers. It’s OK to bend the pins a little to come closer to making contact with the fingers.
13. Use the guide lines (etched into the acrylic) to guide the placement of the strip as the paper backing is removed and the strip is attached to the acrylic (refer to the following picture).

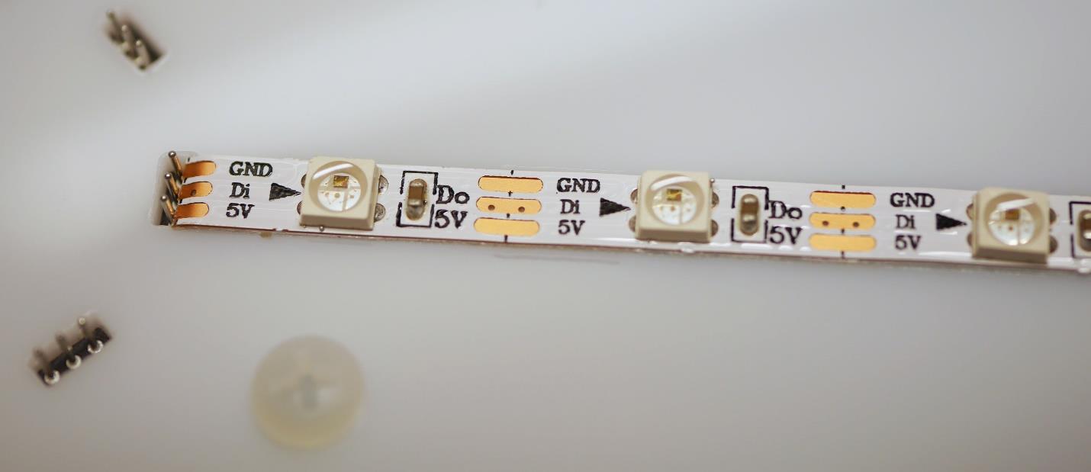
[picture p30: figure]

14. Repeat steps 9 through 13 until all strips have been attached.
15. Solder the exposed copper fingers to the pin headers.
16. Carefully remove screws and standoffs, one at a time, and switch the sides where they’re attached. The screw should now be on the StarLiteMain board and the standoff on the inner acrylic star. Repeat with the other three screw/standoff sets.
17. Remove the protective paper from both sides of the outer star.
18. Place the outer star on top of the standoffs and screw it on. The assembly should look like the following picture.

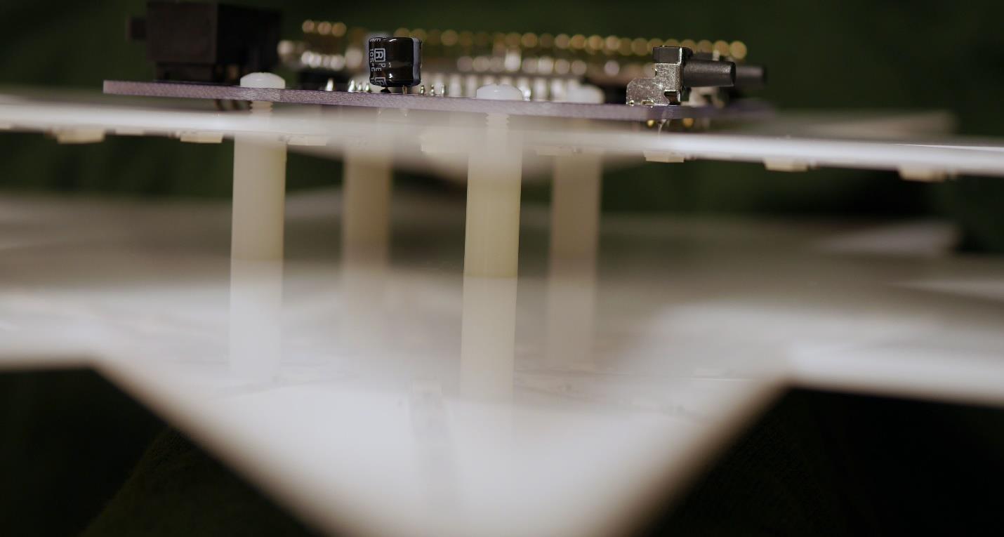
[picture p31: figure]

## Optional 3D Printed Back Cover

To give Starlite a more finished look, one can add a back cover. The also makes the Starlite more stable when placed standing up. Alternatively, the back cover has a feature which allows it to be mounted to a wall.

The files for the back cover are found in the “Mechanical” folder. There’s one for the 6-point and one for the 8-point designs.

The following picture shows the back cover for the 6-point Starlite. Labels were also added for clarity.

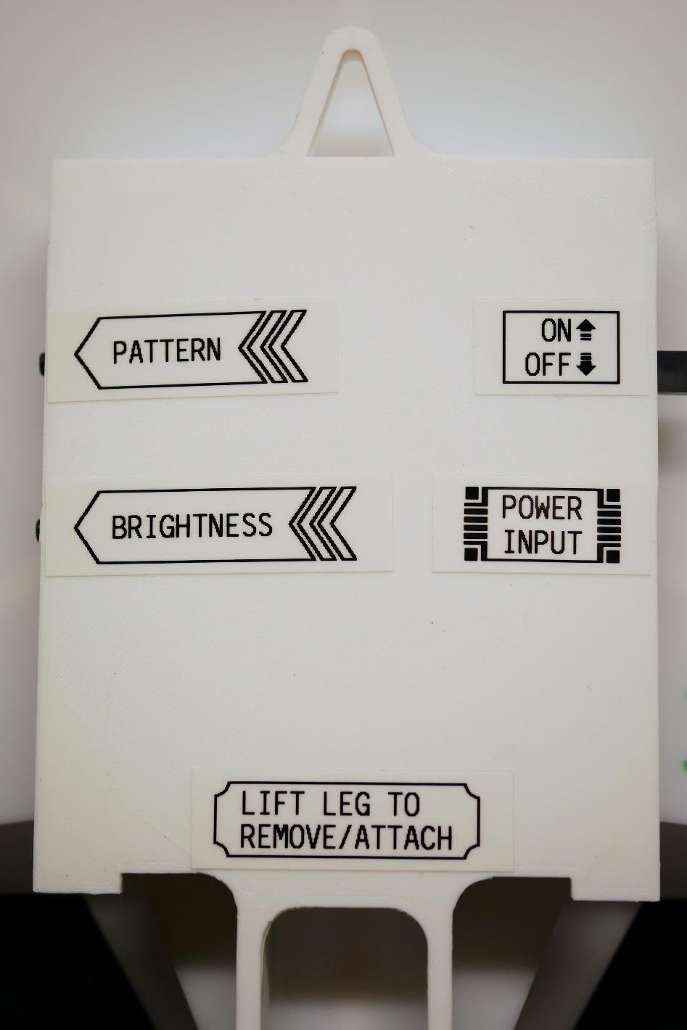
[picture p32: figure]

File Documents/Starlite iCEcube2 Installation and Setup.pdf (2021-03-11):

# Starlite Installation & Setup Using

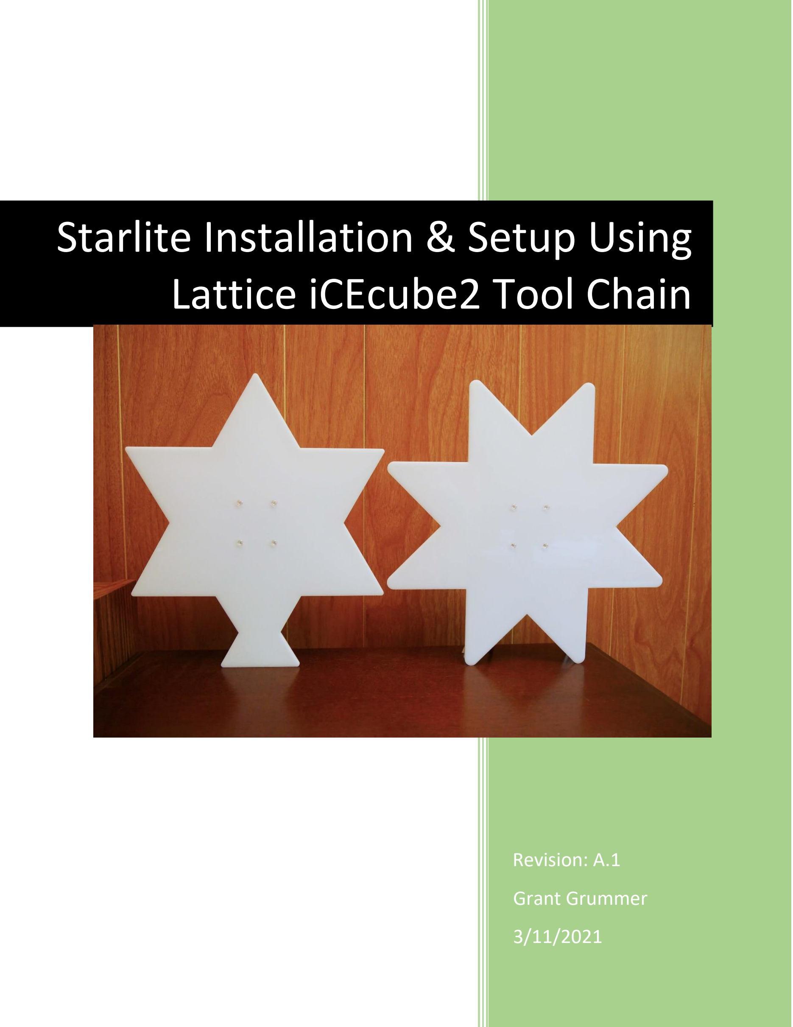
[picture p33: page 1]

## Grant Grummer

3/11/2021

# Lattice iCEcube2 Tool Chain

## Revision: A.1

## Starlite Installation & Setup

## Table of Contents

## Introduction

Welcome to the Starlite project setup. Whether you’re planning to build the 6 or 8-point star, the follow information will help you on your way. This document covers Windows installations only.

## Build Tools

The design was built using the Lattice Semiconductor iCEcube2 platform. There are other tools one could use, but that would require significant changes to the supplied code. iCEcube2 is free and is available on the Lattice website at:

http://www.latticesemi.com/Products/DesignSoftwareAndIP/FPGAandLDS/iCEcube2

You’ll find useful documentation on that web page. The “iCEcube2_install_overview” document has important installation and license information. A license is required to run iCEcube2. The link to obtaining a license is also at the above website. Follow the license link. You’ll be asked to sign in to your account. If you don’t have one, you’ll need to create by selecting the “Create Account” link.

Once a license is obtained, download and install iCEcube2. In order to use the supplied Windows batch files as is, install iCEcube2 into the following path: “C:\Tools\lscc”. Otherwise one can modify the batch files with a different install path.

## Creating a Project

Start the iCEcube2 software. The iCECube2 main window appears, as shown in Figure 1.

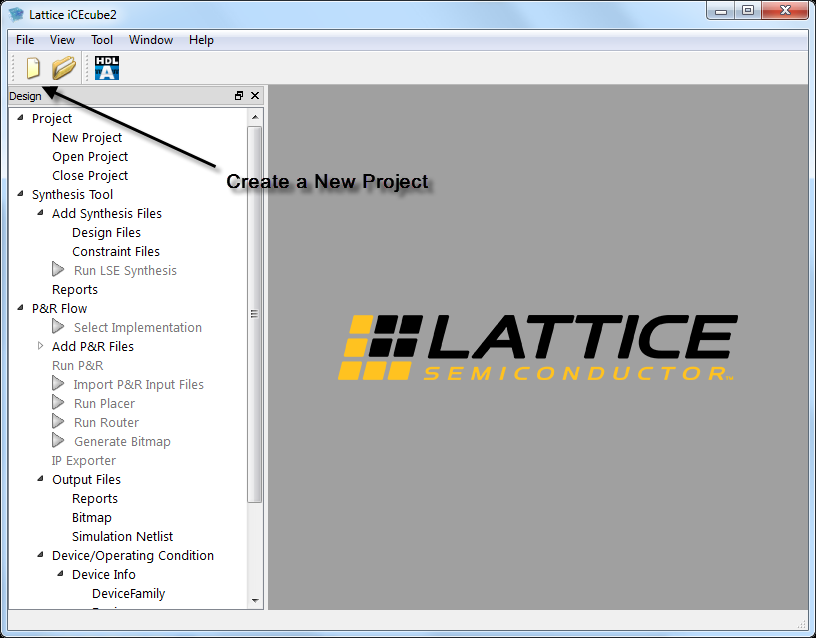
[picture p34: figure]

Figure 1: iCEcube2 Main Window

To create a new project, choose File > New, or click the Create a New Project icon as shown in Figure 1. This will launch the New Project Wizard, as shown in Figure 2. Make the changes indicated (in Figure 2) to the Project, Device and IO Bank Voltage sections.

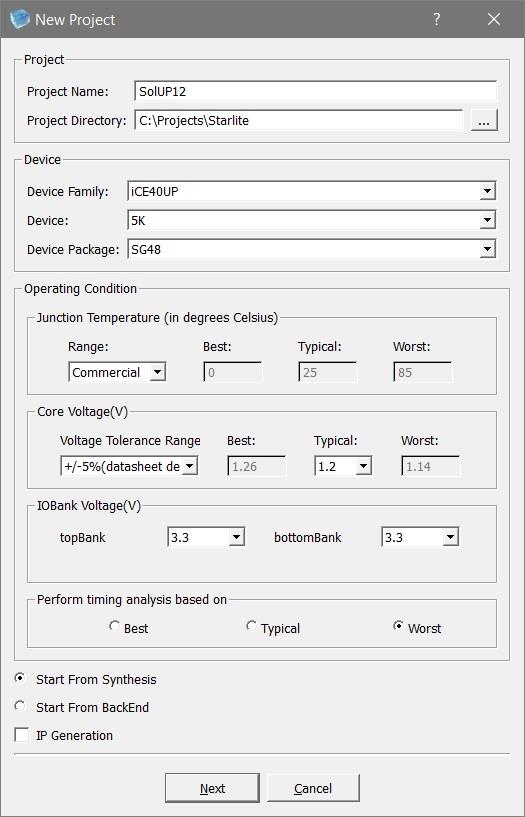
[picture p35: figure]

Figure 2: New Project Wizard

Click Next to display the Add Files dialog box.

Select Finish (we’ll add the files later).

## Download Starlite Files

The Starlite files are located in GitHub. In order to download the files, one clones the directories using “GitHub Desktop”. (https://desktop.github.com/) Once GitHub Desktop is installed, the Starlite project is located at:

https://github.com/ggrummer/Starlite

Place the following folders in “..Starlite\ SolUP12\SolUP12_Implmnt\sbt”:

- constraint
- netlist
- outputs
- patterns
- rtl
- TestBenchs

The rest of the folders should be placed in the “Starlite” directory.

## Next Steps

### Quick Custom Displays

A quick way to get started with Starlite is to make your own custom displays. If that’s the plan, there’s no need to continue with the installation. If desired one can always continue at a later time. Refer to the “Starlite User’s Manual” section on “Quick Custom Displays” for further instructions.

### Altering the Code

If the plan is the alter the code, iCEcube2 will need to know where to find the code and constraints. The following sections will cover how to this.

## Adding Files to The Project

### Select a synthesis tool

The project was built using the “Lattice LSE” synthesis engine. In the project panel, on the left side of the iCEcube2 window, right click on “Synthesis Tool” and select “Select Synthesis Tool…”. Select “Lattice LSE” and click OK.

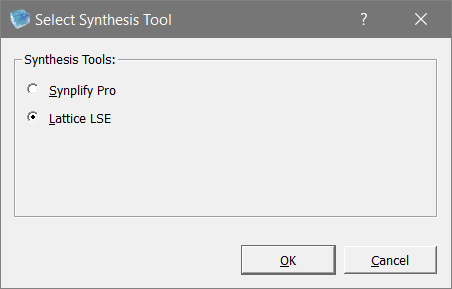
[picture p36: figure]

Figure 3: Selecting the Synthesis Tool

### Add Design Files

Under “Synthesis Tool” is “Add Synthesis Files” and under that are “Design Files” and “Constraints Files”. Right click on “Design Files” and select “Add Files…”.

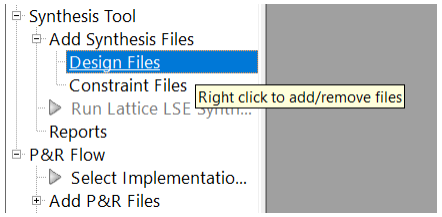
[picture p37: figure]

Figure 4: Where to Add Design Files

Add all the files in the “rtl” directory by selecting the “>>>” button.

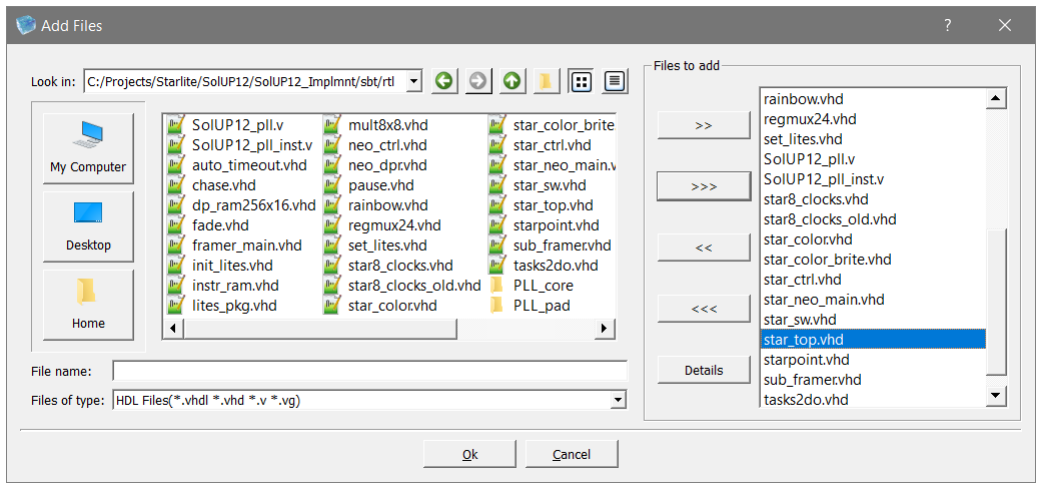
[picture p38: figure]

Figure 5: Add the Files

The top-level design file must be at the bottom of the list. There’s no straight forward way to do this so select “star_top.vhd” in the right most “Files to add” window. Select “<<” to remove it. Now select “star_top.vhd” in the right most window. Select “>>” to re-add it. Now it will show up in the bottom of the list. Now select “Ok”.

### Add Constraint Files

Right click on “Constraints Files” and select “Add Files…”. Add “star.sdc” from the “constraint” directory by selecting “>>” to add it. Select “Ok”.

Right click on “Add P&R Files” and select “Add Files…”. Add “star.pcf” from the “constraint” directory by selecting “>>” to add it. Select “Ok”.

## Building the Design

Instructions for building the design are covered in the “Starlite User’s Manual”. Refer to the “Run Synthesis” section to start the build.

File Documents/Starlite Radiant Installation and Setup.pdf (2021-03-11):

# Starlite Installation & Setup Using

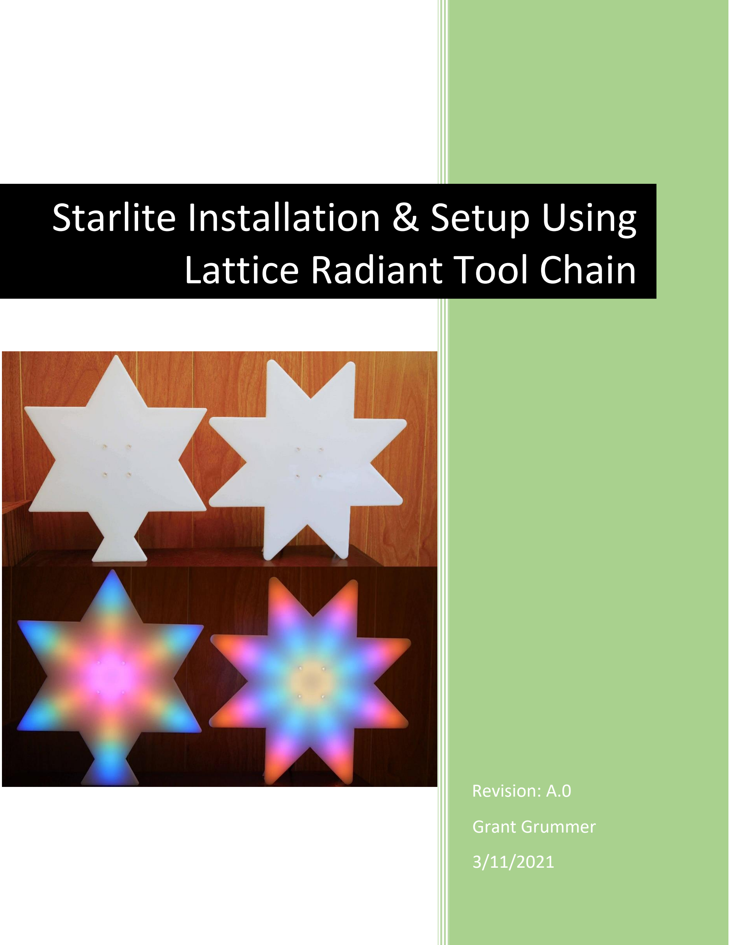
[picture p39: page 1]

## Grant Grummer

3/11/2021

# Lattice Radiant Tool Chain

## Revision: A.0

## Starlite Installation & Setup

1

## Table of Contents

## Introduction

Welcome to the Starlite project setup. Whether you’re planning to build the 6 or 8-point star, the follow information will help you on your way. This document covers Windows installations only.

## Build Tools

The design was built using the Lattice Semiconductor Radiant platform. There are other tools one could use, but that would require significant changes to the supplied code. Radiant is free and is available on the Lattice website at:

http://www.latticesemi.com/Products/DesignSoftwareAndIP/FPGAandLDS/Radiant

You’ll find useful documentation on that web page. The Radiant Software Installation Guide document has important installation and license information. A license is required to run Radiant. The link to obtaining a license is also at the above website. Follow the license link. You’ll be asked to sign in to your account. If you don’t have one, you’ll need to create by selecting the “Create Account” link.

Once a license is obtained, download and install Radiant. When the “Select Component(s)” window opens, the only FPGA device you’ll need is the “Lattice iCE40UP”, though it’s ok to install more devices if desired.

## Download Starlite Files

The Starlite files are located in GitHub. In order to download the files, one clones the directories using “GitHub Desktop”. (https://desktop.github.com/) Once GitHub Desktop is installed, the Starlite project is located at:

https://github.com/ggrummer/Starlite

Place all the files and directories in a new directory. The design was built using the following root directory structure: “C:\Projects\Starlite\SolRadi”. It may be OK to use a different directory structure, but that hasn’t been tested

## Building the Design for the First Time

Start the Radiant program. Double click on the “Open Project” icon. See Figure 1.

## Starlite Installation & Setup

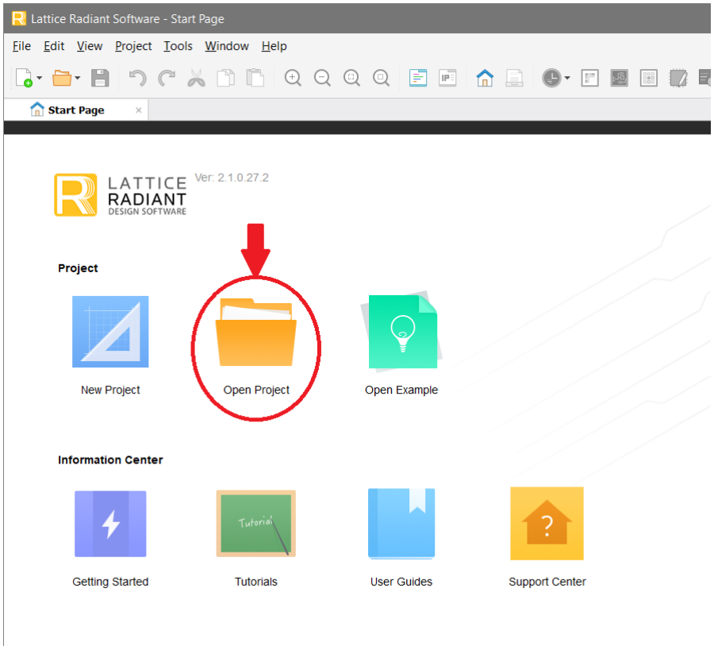
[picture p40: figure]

2

Figure 1: Open Project Window

Navigate to the “SolRadi” directory and select the “Sol12.rdf” file. The Lattice Radiant Software main

window will open. Click on the “Run All” triangle. The boxes to the right of the “Run All” triangle all turn green (with a check mark) once the design has been built.

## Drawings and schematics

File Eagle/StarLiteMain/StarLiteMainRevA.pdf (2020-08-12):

# 19 U2¹⁰ ²⁰ GND VCC U2P

A

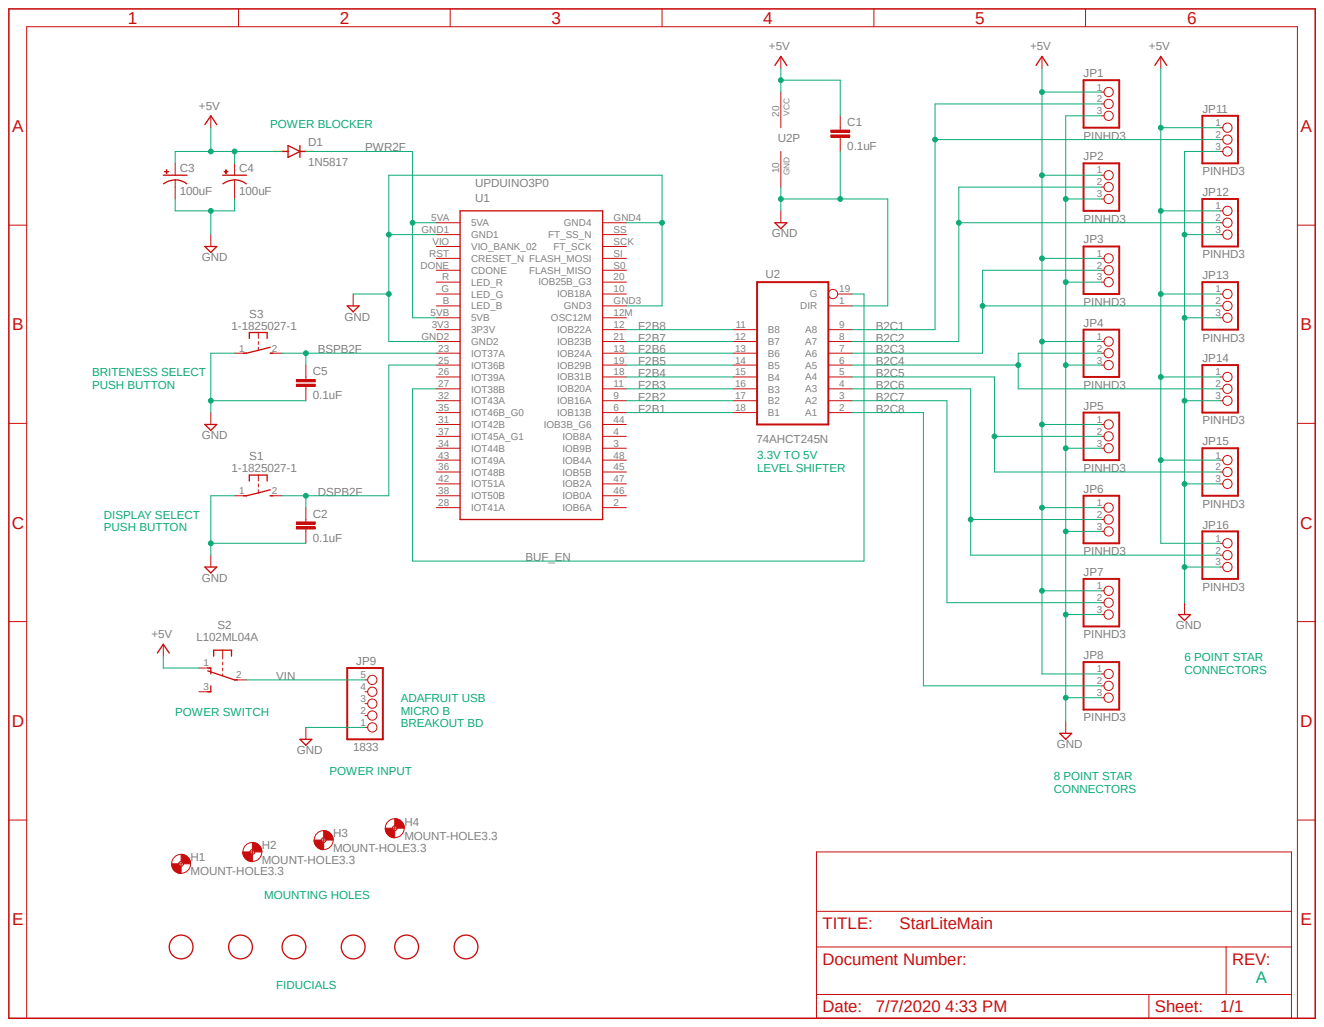
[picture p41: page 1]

IOT37A 23 IOT36B 25 | F2B6 | B2C3

Document Number: | REV: A

Date: 7/7/2020 4:33 PM | Sheet: 1/1

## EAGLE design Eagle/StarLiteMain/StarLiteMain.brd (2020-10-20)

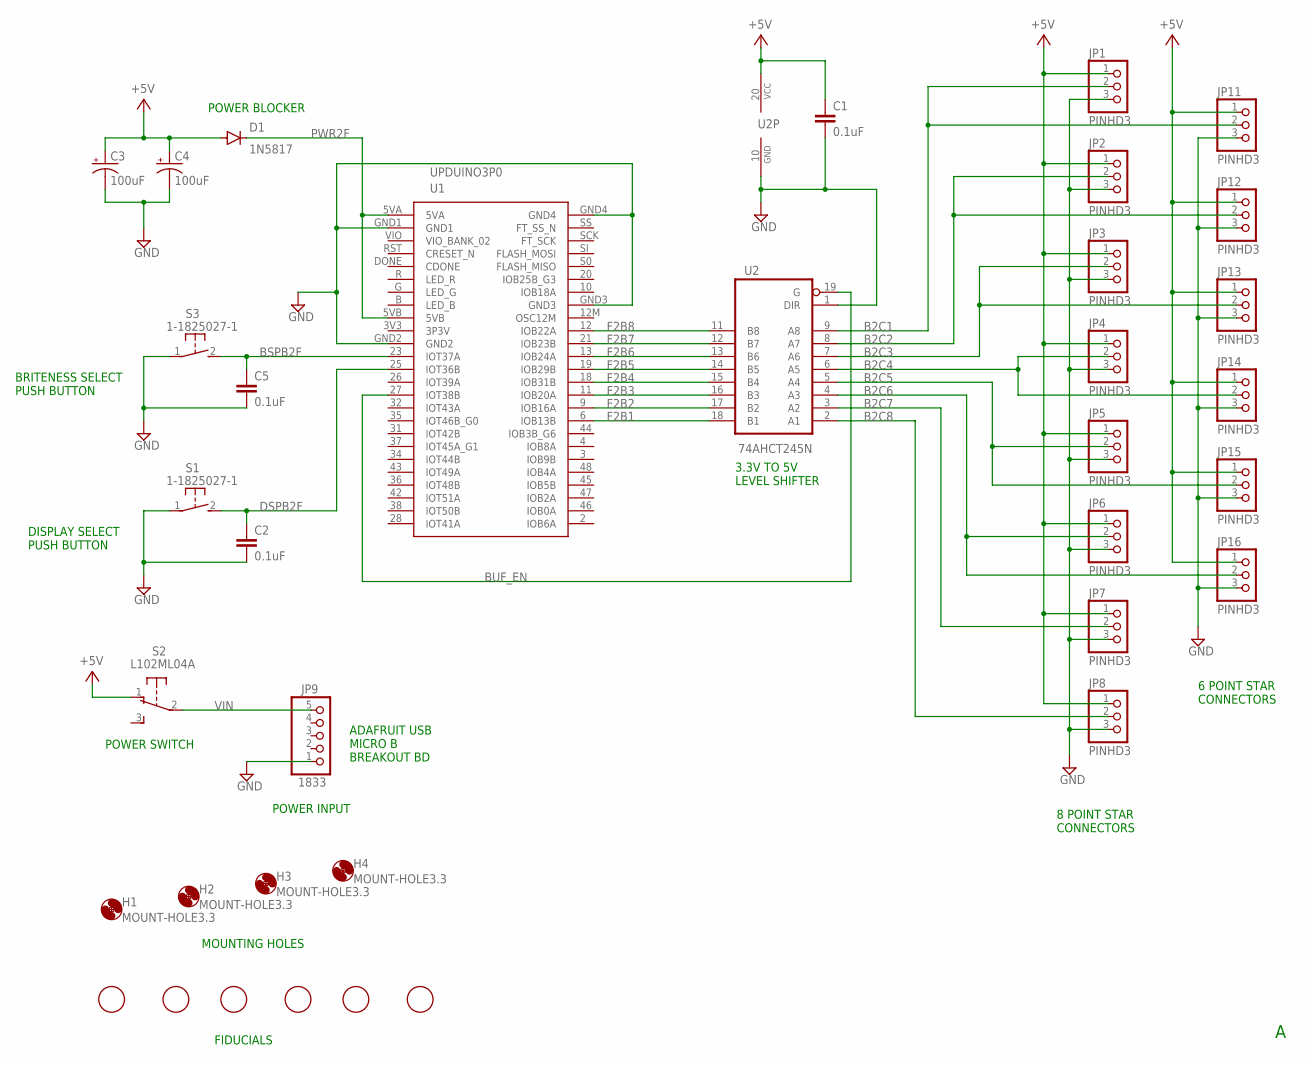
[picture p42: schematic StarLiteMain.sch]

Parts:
C1, C2, C5: 0.1uF; C2.5-3
C3, C4: 100uF; E2,5-6
D1: 1N5817; DO41-10
H1, H2, H3, H4: MOUNT-HOLE3.3; 3,3
JP1, JP2, JP3, JP4, JP5, JP6, JP7, JP8, JP11, JP12, JP13, JP14, JP15, JP16: PINHD3; 1X03_50MIL
JP9: 1833; 1X05
S1, S3: 1-1825027-1; B3F-31XX
S2: L102ML04A; SPDT187
U1: UPDUINO3P0
U2: 74AHCT245N; DIL20
U$1, U$2, U$3, U$4, U$5, U$6: FIDUCIAL; FIDUCIAL_1MM

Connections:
+5V: C1.1, C3.+, C4.+, D1.A, JP1.1, JP2.1, JP3.1, JP4.1, JP5.1, JP6.1, JP7.1, JP8.1, JP11.1, JP12.1, JP13.1, JP14.1, JP15.1, JP16.1, S2.1 (O), U2.20 (VCC)
B2C1: JP1.2, JP11.2, U2.9 (A8)
B2C2: JP2.2, JP12.2, U2.8 (A7)
B2C3: JP3.2, JP13.2, U2.7 (A6)
B2C4: JP4.2, JP14.2, U2.6 (A5)
B2C5: JP5.2, JP15.2, U2.5 (A4)
B2C6: JP6.2, JP16.2, U2.4 (A3)
B2C7: JP7.2, U2.3 (A2)
B2C8: JP8.2, U2.2 (A1)
BSPB2F: C5.1, S3.2 (S), U1.23 (IOT37A)
BUF_EN: U1.27 (IOT38B), U2.19 (G)
DSPB2F: C2.1, S1.2 (S), U1.25 (IOT36B)
F2B1: U1.6 (IOB13B), U2.18 (B1)
F2B2: U1.9 (IOB16A), U2.17 (B2)
F2B3: U1.11 (IOB20A), U2.16 (B3)
F2B4: U1.18 (IOB31B), U2.15 (B4)
F2B5: U1.19 (IOB29B), U2.14 (B5)
F2B6: U1.13 (IOB24A), U2.13 (B6)
F2B7: U1.21 (IOB23B), U2.12 (B7)
F2B8: U1.12 (IOB22A), U2.11 (B8)
GND: C1.2, C2.2, C3.-, C4.-, C5.2, JP1.3, JP2.3, JP3.3, JP4.3, JP5.3, JP6.3, JP7.3, JP8.3, JP9.1, JP11.3, JP12.3, JP13.3, JP14.3, JP15.3, JP16.3, S1.1, S3.1, U1.GND1, U1.GND2, U1.GND3, U1.GND4, U2.1 (DIR), U2.10 (GND)
PWR2F: D1.C, U1.5VA, U1.5VB
VIN: JP9.5, S2.2

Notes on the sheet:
POWER INPUT
POWER SWITCH
POWER BLOCKER
3.3V TO 5V LEVEL SHIFTER
DISPLAY SELECT PUSH BUTTON
ADAFRUIT USB MICRO B BREAKOUT BD
8 POINT STAR CONNECTORS
6 POINT STAR CONNECTORS
MOUNTING HOLES
FIDUCIALS
BRITENESS SELECT PUSH BUTTON

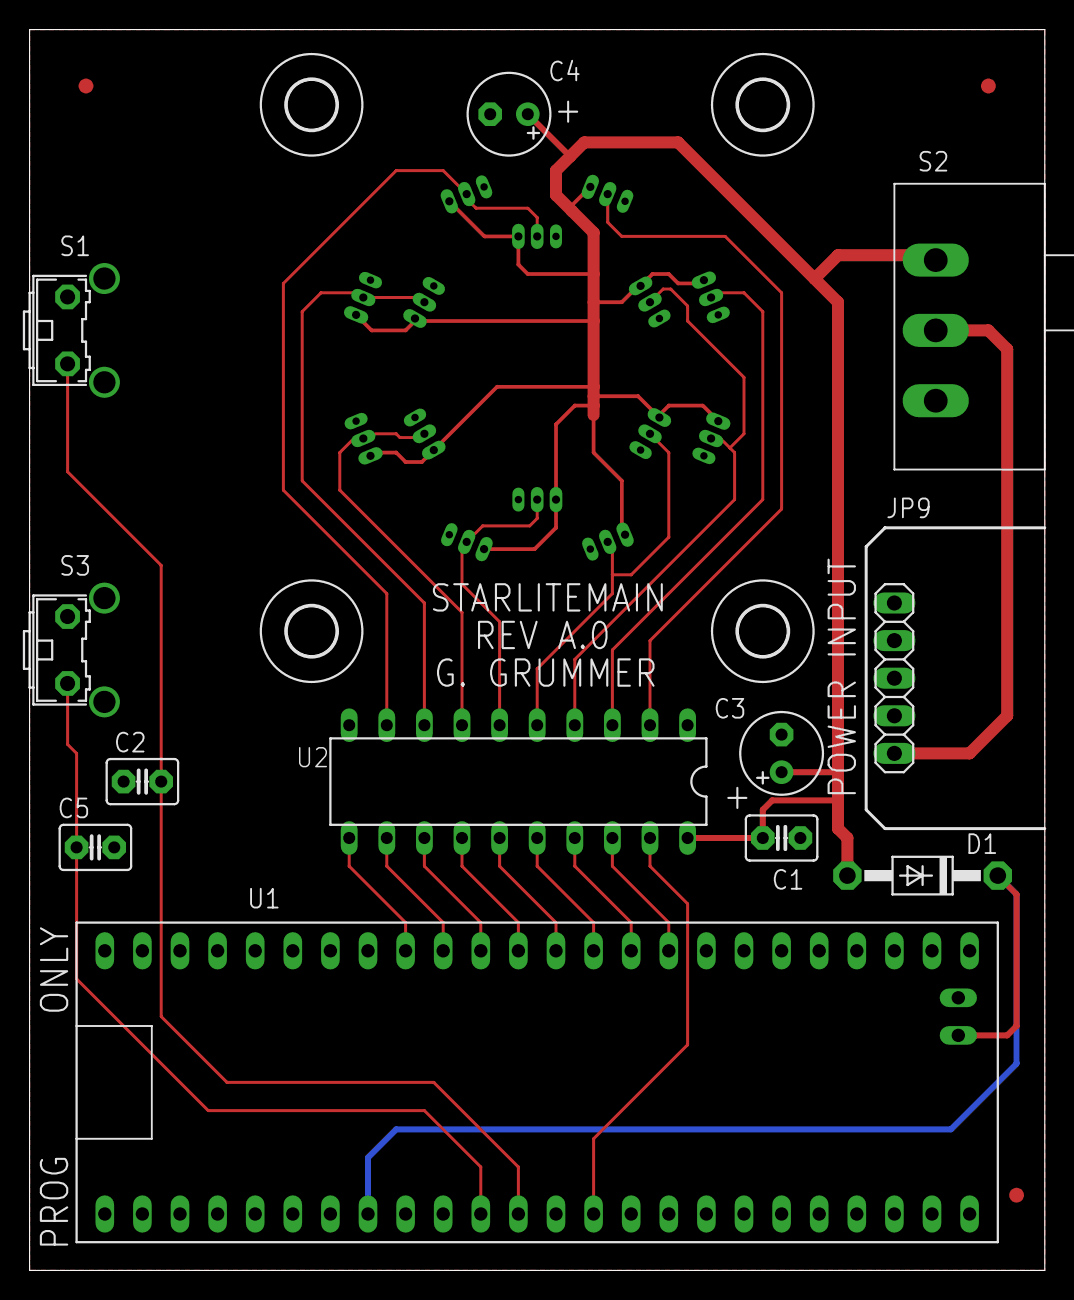
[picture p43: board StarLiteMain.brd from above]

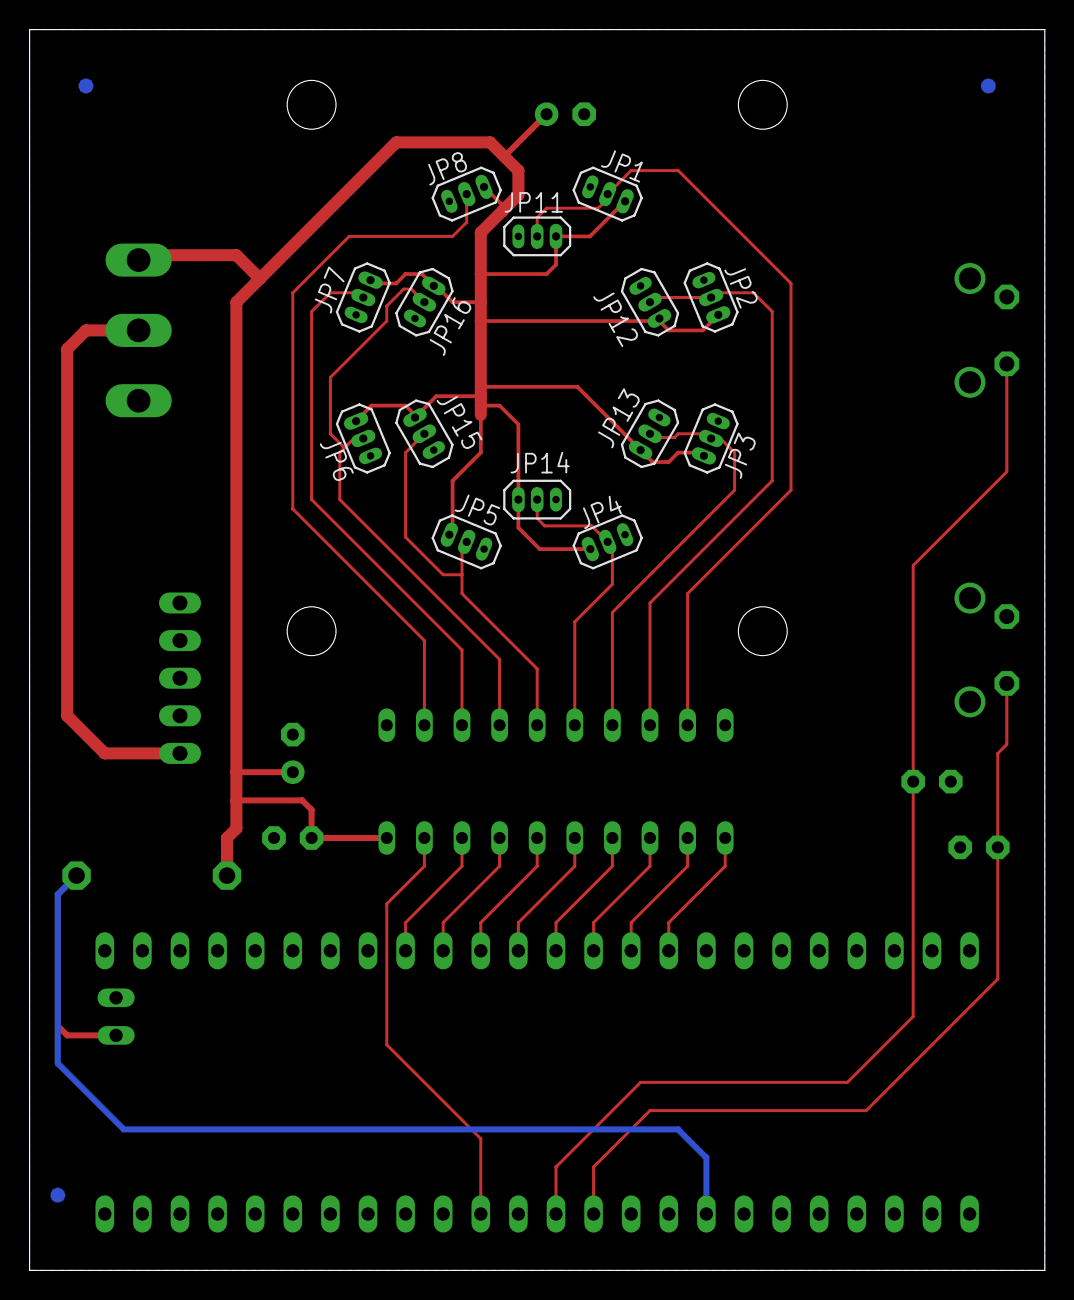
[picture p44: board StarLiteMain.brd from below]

Board: 2 copper layers, 68.6 x 83.8 mm, 36 parts (17 on the bottom side), 23 nets.

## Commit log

2020-08-12 Added documents and PCB project
    Added documentation and the Eagle PCB project files.
    [LED_StarLiteUP_Instruction.xlsx, StarLiteMain.brd, StarLiteMain.sch]
2020-08-12 Acrylic Stars
    Added DXF file for laser cutting the acrylic stars
    [InStar6c305.dxf, InStar8SymC.dxf, OutStar6b305.dxf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]
2020-08-12 Create starliteBOM.xlsx
    Added the project parts list
    [starliteBOM.xlsx]
2020-08-14 Update LED_StarLiteUP_Instruction.xlsx
    Eliminated footnote 2. It no longer applies.
    [LED_StarLiteUP_Instruction.xlsx]
2020-08-25 Added documentation
    Added initial versions of user's manual and installation guide. Updated block diagram. Added notes to the parts list.
    [starliteBOM.xlsx]
2020-09-08 Updated User's Manual
    Updated User's Manual and deleted redundent documents. The parts list was moved to documents and the Parts directory was deleted.
    [starliteBOM.xlsx, starlitePL.xlsx]
2020-09-11 Additions and cleanup
    Added assembly instructions. Added instruction descriptions to user's manual. Cleaned up spreadsheet.
    [LED_StarLiteUP_Instruction.xlsx]
2020-09-13 Added Back Cover CAD Files
    Added back cover 3D printer CAD Files. Both the STL files and the OnShape CAD file links are included.
    [StarCoverMain6b.stl, StarCoverMain8b.stl]
2020-09-13 Update README.md
    Added notes about the board and mechanical directories.
2020-09-14 Update Starlite Assembly Instructions.pdf
    Clarified which pins on the UPduino board must be soldered to the StarLiteMain board.
2020-09-24 Added Gerber Files
    [copper_bottom.gbr, copper_top.gbr, drill_1_16.xln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]
2020-10-03 Update Starlite Assembly Instructions.pdf
    Fixed typos.
2020-10-20 Moved 5V & GND Holes
    Moved 5V & GND hole pair
    [StarLiteMain.brd, StarLiteMain.sch]
2020-10-20 Moved 5V & GND Hole Pair
    [copper_bottom.gbr, copper_top.gbr, drill_1_16.xln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]
2020-12-13 Update starlitePL.xlsx
    Fixed typo
    [starlitePL.xlsx]
2021-03-10 Reorganized/Added FPGA files
    Moved iCEcube2 FPGA files into SolUP12 directory.
    Added Radiant FPGA files to SolRadi directory.
    [instr_dpram_sect0.cfg, instr_dpram_sect1.cfg, instr_dpram_sect2.cfg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]
2021-04-29 Expanded Chase module features
    [LED_StarLiteUP_Instruction.xlsx]
2021-05-11 Sides for 8 point star
    Added 3D printed side files for the 8 point star.
    [Bot8Side.stl, Left8Side.stl, Right8Side.stl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]
2021-05-24 Side Cover Additions
    Added 6 point star sides. Modified 6 & 8 point back covers to work with star sides.
    [Left6All.stl, Right6All.stl, StarCoverMain6b.stl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]
2021-05-24 Update README.md
    Added 3D printed side covers.
2021-05-28 Update starlitePL.xlsx
    Listed alternatives for obsolete LED string.
    [starlitePL.xlsx]
2021-05-28 Update StarCoverMain8c.stl
    Made a little bit more space between the sections that the legs mount to. Needed to fit the sides better.
    [StarCoverMain8c.stl]
2021-05-30 Update Right6All.stl
    Increased diameter of locking feature between right and left side prints by 0.005".
    [Right6All.stl]
2021-06-04 Update starlitePL.xlsx
    Added more details on replacement LED strips.
    [starlitePL.xlsx]
2021-12-13 Reversed individual point blocking order
    Reversed individual point blocking order so point 0 was the first physical point.
    [instr_dpram_sect0.cfg, instr_dpram_sect1.cfg, instr_dpram_sect2.cfg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]
2022-04-17 Sides for 1/8" Inner Acrylic
    Added files for Starlite sides using 1/8" thick inner acrylic.
    [Bot88Side.stl, Left88Side.stl, Right88Side.stl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]
2022-06-09 Excluded Color Repeats
    When using random colors (in instruction 3) one can now choose whether to allow them to repeat or to exclude repeats.
    [LED_StarLiteUP_Instruction.xlsx]
2025-02-05 STL files for 1/16" thick inner acrylic
    STL files for 1/16" thick inner acrylic
